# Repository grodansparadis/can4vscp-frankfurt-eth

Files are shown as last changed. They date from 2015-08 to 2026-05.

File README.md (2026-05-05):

<h1>CAN4VSCP Frankfurt Eth (PoE)</h1>

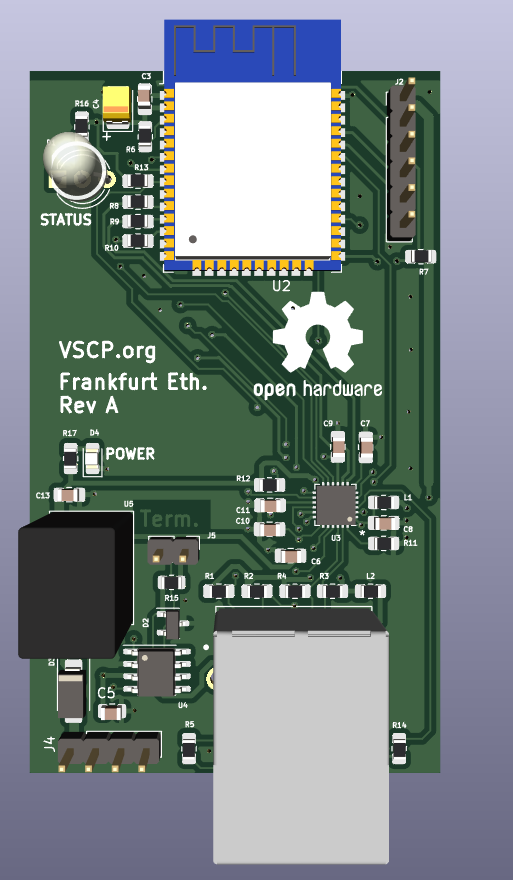
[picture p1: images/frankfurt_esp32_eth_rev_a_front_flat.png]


This work is based on original work done [here](https://github.com/nuclearcat/ESP32ETH). 

**Frankfurt Eth** is a tcp/ip and MQTT CAN4VSCP gateway. The module is available in two versions. One without PoE and and one with PoE.

The module is plug and play. Just connect to a CAN4VSCP system and go to work. You can connect to the module using [VSCP tcp/ip link protocol](https://grodansparadis.github.io/vscp-doc-spec/#/./vscp_tcpiplink) or set it up to talk to a MQTT broker of choice.

Note that this is **not** a CAN <-> tcp/ip (or MQTT) gateway as it only speaks [VSCP](https://grodansparadis.github.io/vscp-doc-spec). It is possible though to load firmware into it to create a standard CAN (not CAN FD) <-> tcp/ip gateway. 

The project uses an ESP32 Wroom module. It utilize Ethernet instead of Wifi/Bluetooth. Ethernet interface is provided with a LAN8720A and CAN is provided by the ESP32 support for TWAI. The module is powered from the [CAN4VSCP bus](https://grodansparadis.github.io/vscp-doc-spec/#/./vscp_over_can_can4vscp) (or PoE).  When powered from PoE the module can provide power for other CAN4VSCP modules. CAN4VSCP power is in the range +9V - 28V.

The intended use is to connect a remote CAN4VSCP bus to a central system or to connect two or more CAN4VSCP networks together. 

If Wifi is required instead of Ethernet the [CAN4VSCP Frankfurt Wifi module](https://github.com/grodansparadis/can4vscp-frankfurt-wifi) is available that can do that.



Prototype PCB's for this project has been sponsored by [PCBWay](https://www.pcbway.com/). We can really recommend this service if you need high quality PCB's. 

## Schema

### Standard version

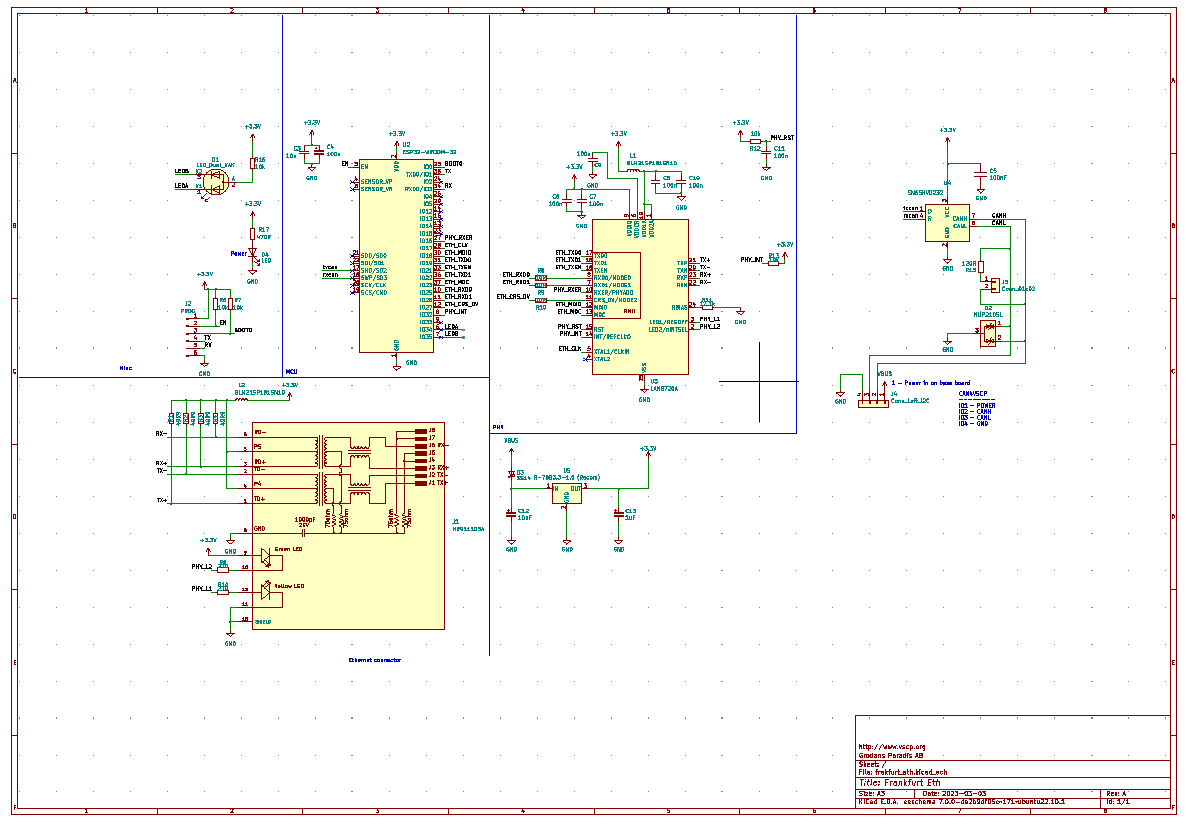
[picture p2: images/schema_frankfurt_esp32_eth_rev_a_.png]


### PoE version

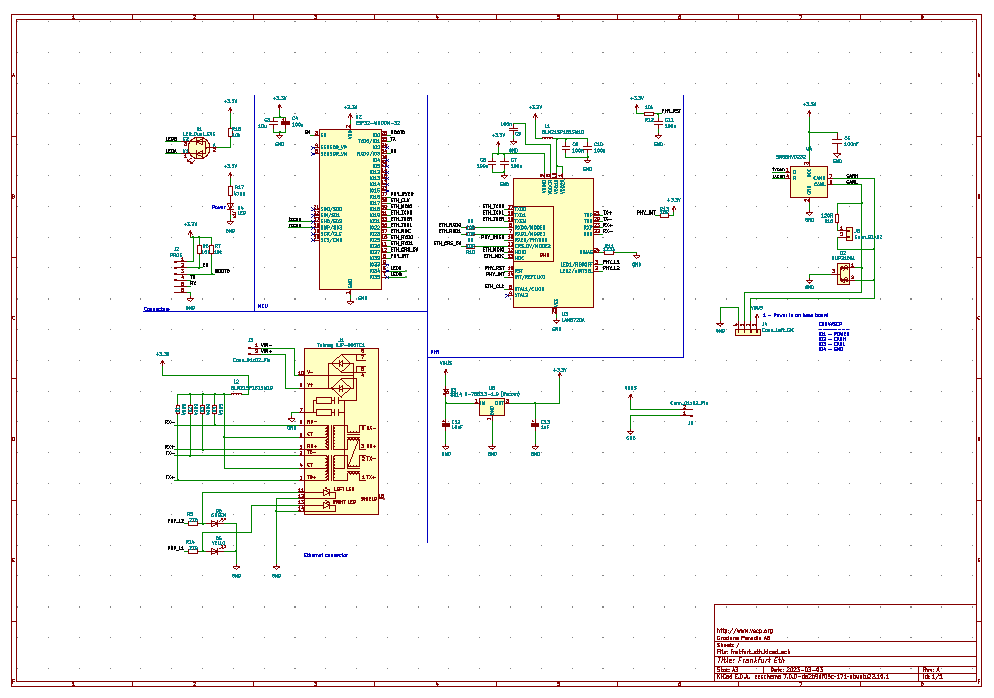
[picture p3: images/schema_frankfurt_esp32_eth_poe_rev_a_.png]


## Standard version

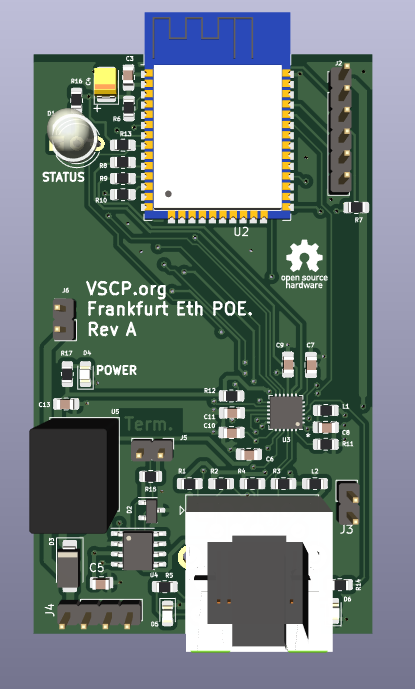
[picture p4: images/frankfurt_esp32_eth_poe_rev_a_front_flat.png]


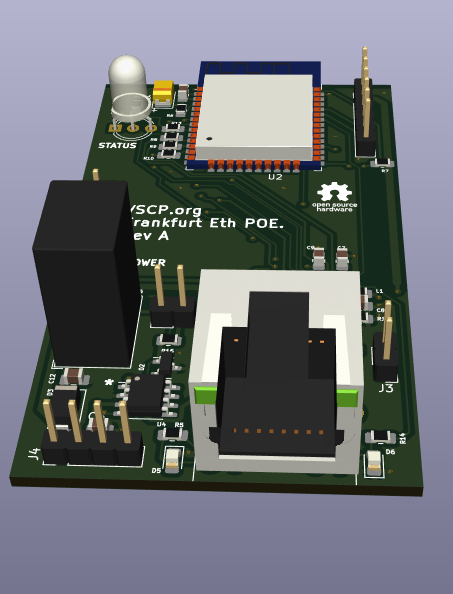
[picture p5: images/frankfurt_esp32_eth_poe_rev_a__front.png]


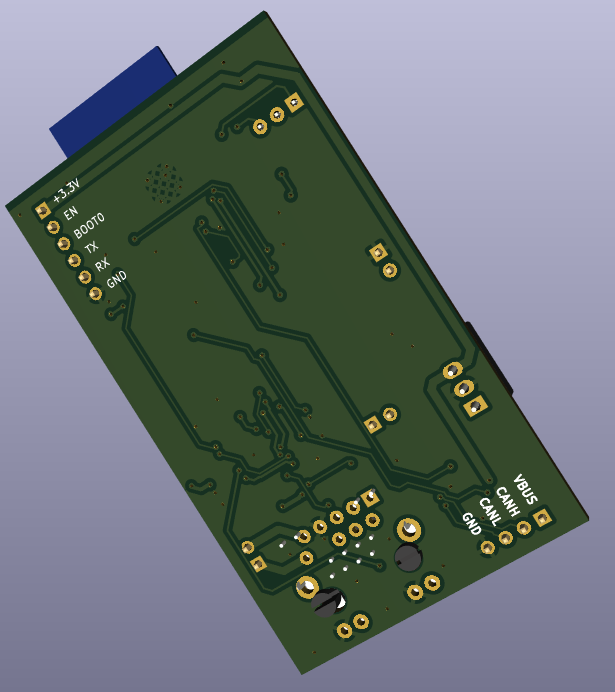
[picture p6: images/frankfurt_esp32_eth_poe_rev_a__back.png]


## PoE Version



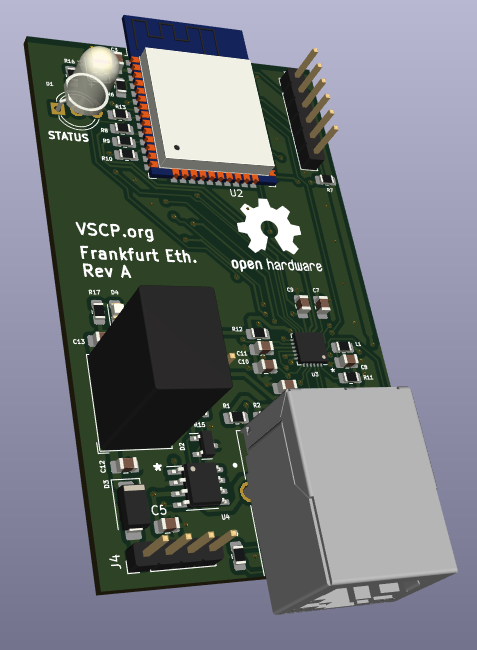
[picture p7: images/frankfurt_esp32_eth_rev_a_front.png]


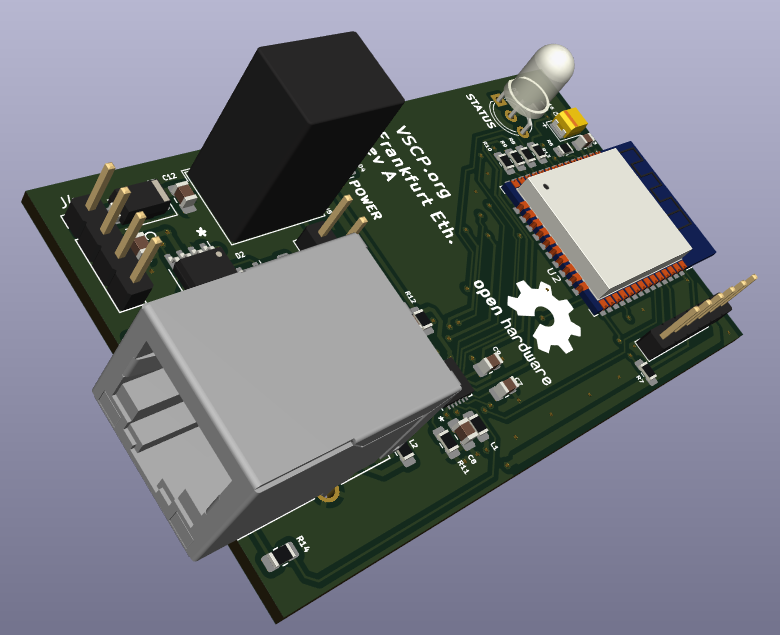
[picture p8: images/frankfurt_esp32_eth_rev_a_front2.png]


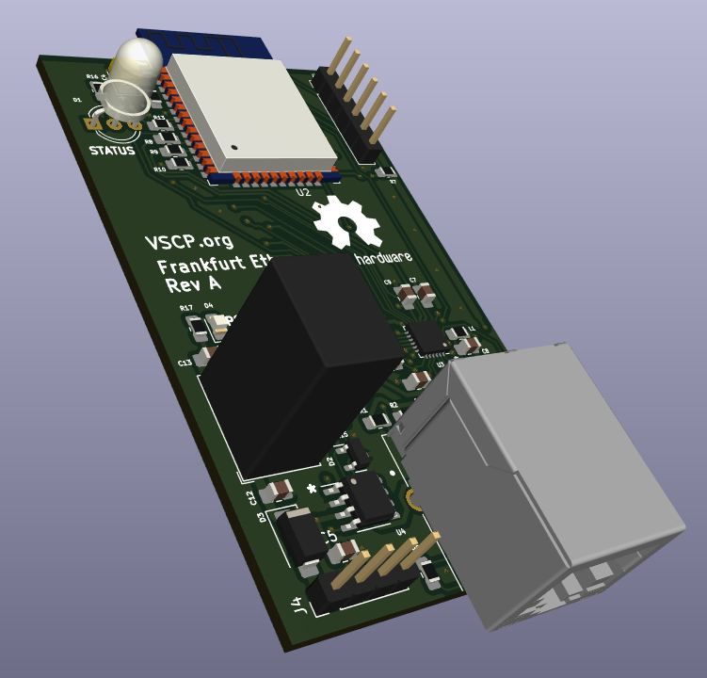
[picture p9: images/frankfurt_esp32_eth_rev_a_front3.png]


<hr>
Please support the <a href="http://www.vscp.org">VSCP development</a>. The best way to support the project is 
to buy something from the <a href="http://www.frogshop.se">FrogShop</a>. If you want to contribute money use the button
 at the end of the <a href="http://www.vscp.org">VSCP sites</a> start page.

Visit our <a href="http://www.vscp.org/wiki/doku.php/sponsors">sponsor page</a> for all options.

<hr>

Part of the VSCP Project.

Copyright 2018-2026 © Åke Hedman, (Grodans Paradis AB)[https://www.grodansparadis.com]

<hr>

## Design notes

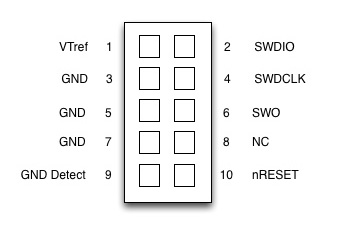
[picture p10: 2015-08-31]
pic-version/docs/swd-jtag-pinout.jpg

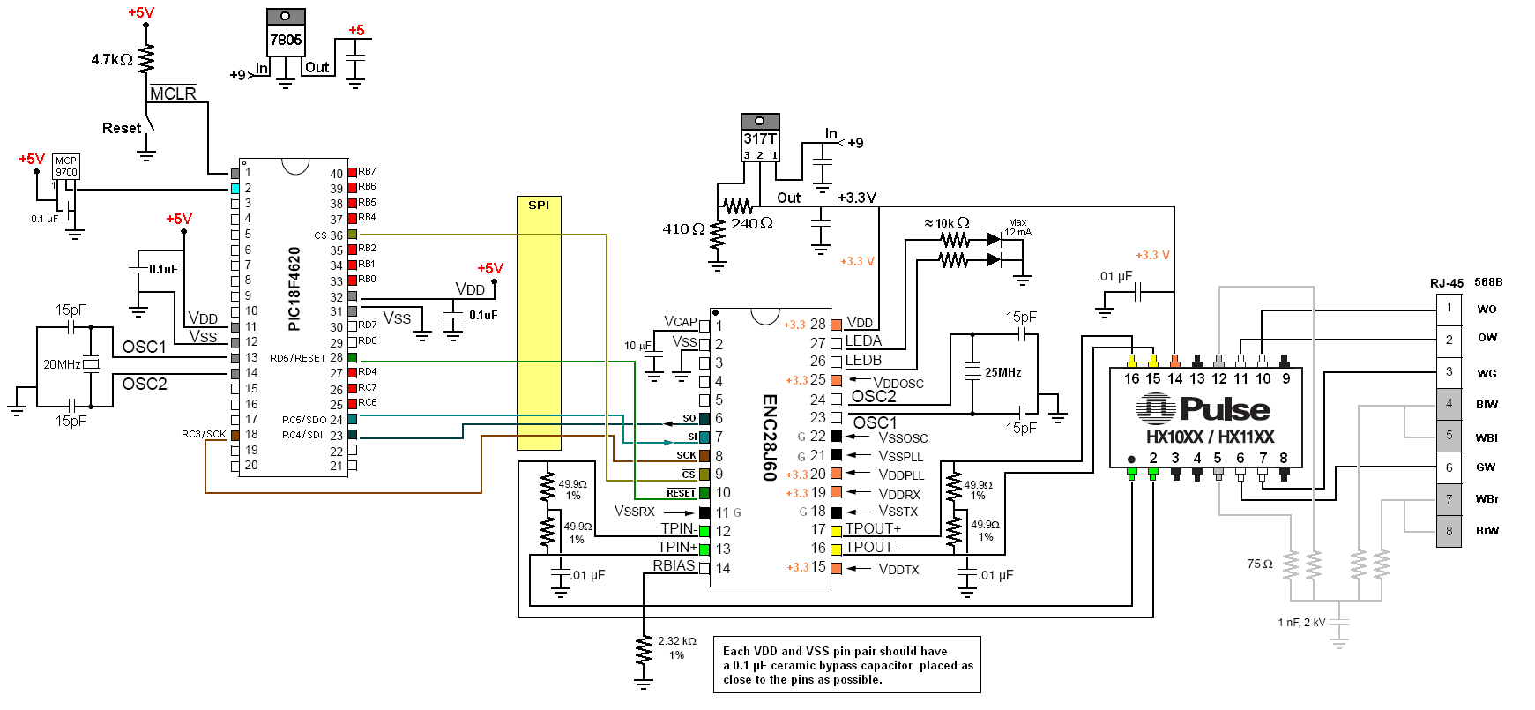
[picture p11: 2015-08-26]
pic-version/docs/eth-schematic-ab.png

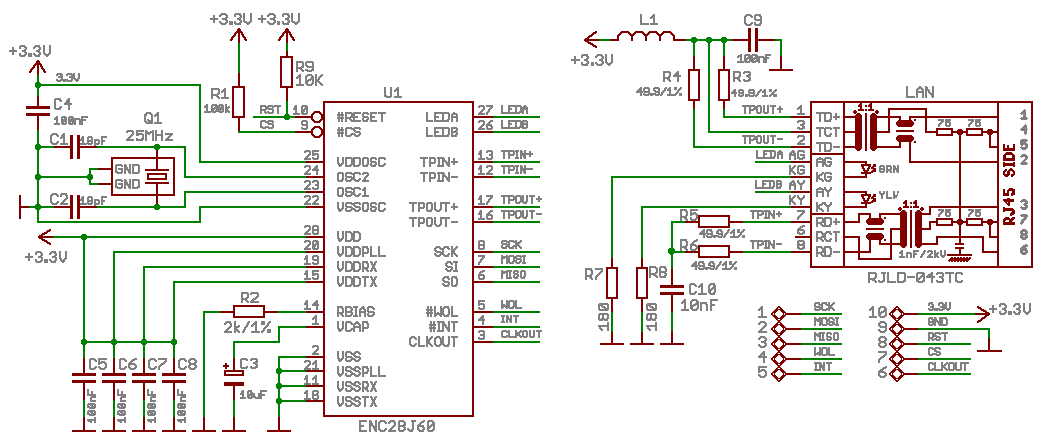
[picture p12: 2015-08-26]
pic-version/docs/enc28j60_h_schematic_full.png

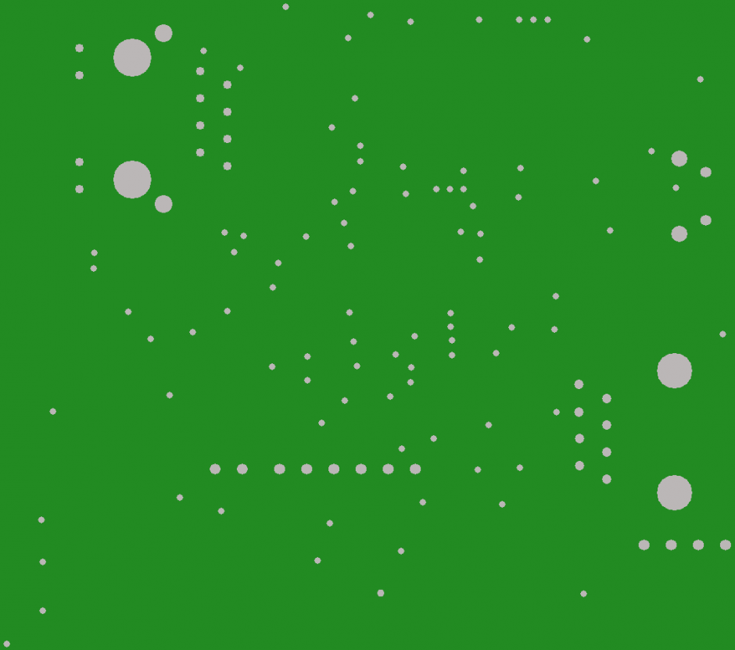
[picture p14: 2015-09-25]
pic-version/eagle/Gerbers/pic/frankfurt_eth_pic_gerbers_150925_txt_small.png

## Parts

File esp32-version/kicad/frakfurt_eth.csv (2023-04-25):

Source: | /usr/local/src/VSCP/can4vscp-frankfurt-eth/esp32-version/kicad/frakfurt_eth.kicad_sch
Date: | tor 23 mar 2023 16:47:27
Tool: | Eeschema 7.0.1-3b83917a11~172~ubuntu22.10.1
Generator: | /usr/share/kicad/plugins/bom_csv_grouped_by_value_with_fp.py
Component Count: | 42
Ref | Qnty | Value | Cmp name | Footprint | Description | Vendor | DNP
C3 | 1 | 10u | C_Small | Capacitor_SMD:C_0805_2012Metric_Pad1.18x1.45mm_HandSolder | Unpolarized capacitor, small symbol
C4 | 1 | 100u | C_Polarized_Small | Capacitor_Tantalum_SMD:CP_EIA-3528-21_Kemet-B | Polarized capacitor, small symbol
C5 | 1 | 100nF | C | Capacitor_SMD:C_0805_2012Metric | Unpolarized capacitor
C6, C7, C8, C9, C10, C11 | 6 | 100n | C_Small | Capacitor_SMD:C_0805_2012Metric_Pad1.18x1.45mm_HandSolder | Unpolarized capacitor, small symbol
C12 | 1 | 10uF | CP_Small | Capacitor_SMD:C_0805_2012Metric_Pad1.18x1.45mm_HandSolder
C13 | 1 | 1uF | CP_Small | Capacitor_SMD:C_0805_2012Metric_Pad1.18x1.45mm_HandSolder
D1 | 1 | LED_Dual_KAK | LED_Dual_KAK | LED_THT:LED_D5.0mm-3 | Dual LED, common anode on pin 2
D2 | 1 | NUP2105L | NUP2105L | Package_TO_SOT_SMD:SOT-23 | Dual Line CAN Bus Protector, 24Vrwm
D3 | 1 | SS14 | D_Schottky_Small | Diode_SMD:D_SMA | Schottky diode, small symbol
D4 | 1 | LED | LED | LED_SMD:LED_0805_2012Metric_Pad1.15x1.40mm_HandSolder | Light emitting diode
J1 | 1 | HR911105A | HR911105A | lib:HANRUN_HR911105A
J2 | 1 | PROG | Conn_01x06_Male | Connector_PinHeader_2.54mm:PinHeader_1x06_P2.54mm_Vertical | Generic connector, single row, 01x06, script generated (kicad-library-utils/schlib/autogen/connector/)
J4 | 1 | Conn_Left_I2C | Conn_01x04 | Connector_PinHeader_2.54mm:PinHeader_1x04_P2.54mm_Vertical | Generic connector, single row, 01x04, script generated (kicad-library-utils/schlib/autogen/connector/)
J5 | 1 | Conn_01x02 | Conn_01x02 | Connector_PinHeader_2.54mm:PinHeader_1x02_P2.54mm_Vertical | Generic connector, single row, 01x02, script generated (kicad-library-utils/schlib/autogen/connector/)
L1, L2 | 2 | BLM21SP181SN1D | L_Small | Resistor_SMD:R_0805_2012Metric_Pad1.20x1.40mm_HandSolder | Inductor, small symbol
R1, R2, R3, R4 | 4 | 49R9 | R_Small | Resistor_SMD:R_0805_2012Metric_Pad1.20x1.40mm_HandSolder | Resistor, small symbol
R5, R14 | 2 | 270 | R_Small | Resistor_SMD:R_0805_2012Metric_Pad1.20x1.40mm_HandSolder | Resistor, small symbol
R6, R7, R12, R13, R16 | 5 | 10k | R_Small | Resistor_SMD:R_0805_2012Metric_Pad1.20x1.40mm_HandSolder | Resistor, small symbol
R8, R9, R10 | 3 | 10R | R_Small | Resistor_SMD:R_0805_2012Metric_Pad1.20x1.40mm_HandSolder | Resistor, small symbol
R11 | 1 | 12.1k | R_Small | Resistor_SMD:R_0805_2012Metric_Pad1.20x1.40mm_HandSolder | Resistor, small symbol
R15 | 1 | 120R | R_Small | Resistor_SMD:R_0805_2012Metric | Resistor, small symbol
R17 | 1 | 470R | R_Small | Resistor_SMD:R_0805_2012Metric_Pad1.20x1.40mm_HandSolder | Resistor, small symbol
U2 | 1 | ESP32-WROOM-32 | ESP32-WROOM-32 | RF_Module:ESP32-WROOM-32 | RF Module, ESP32-D0WDQ6 SoC, Wi-Fi 802.11b/g/n, Bluetooth, BLE, 32-bit, 2.7-3.6V, onboard antenna, SMD
U3 | 1 | LAN8720A | LAN8720A | Package_DFN_QFN:QFN-24-1EP_4x4mm_P0.5mm_EP2.6x2.6mm | LAN8720 Ethernet PHY with RMII interface, QFN-24
U4 | 1 | SN65HVD232 | SN65HVD232 | Package_SO:SOIC-8_3.9x4.9mm_P1.27mm | CAN Bus Transceivers, 3.3V, 1Mbps, SOIC-8
U5 | 1 | R-78B3.3-1.0 (Recom) | R-78B3.3-2.0 | Converter_DCDC:Converter_DCDC_RECOM_R-78B-2.0_THT | 2A Step-Down DC/DC-Regulator, 4.75-32V input, 3.3V fixed Output Voltage, LM78xx replacement, -40°C to +85°C, SIP3

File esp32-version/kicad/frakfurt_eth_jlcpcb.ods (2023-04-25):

Source: | /usr/local/src/VSCP/can4vscp-frankfurt-eth/esp32-version/kicad/frakfurt_eth.kicad_sch
Date: | tor 23 mar 2023 16:47:27
Tool: | Eeschema 7.0.1-3b83917a11~172~ubuntu22.10.1
Generator: | /usr/share/kicad/plugins/bom_csv_grouped_by_value_with_fp.py
Component Count: | 42
Ref | Qnty | Value | Cmp name | Footprint | Description | Vendor | DNP | JLCPCB
C3 | 1 | 10u | C_Small | Capacitor_SMD:C_0805_2012Metric_Pad1.18x1.45mm_HandSolder | Unpolarized capacitor, small symbol |  |  | 0.18 | 0.1793
C4 | 1 | 100u | C_Polarized_Small | Capacitor_Tantalum_SMD:CP_EIA-3528-21_Kemet-B | Polarized capacitor, small symbol |  |  | 0.01 | 0.0057
C5 | 1 | 100nF | C | Capacitor_SMD:C_0805_2012Metric | Unpolarized capacitor |  |  | 0.0057 | 0.0057
C6, C7, C8, C9, C10, C11 | 6 | 100n | C_Small | Capacitor_SMD:C_0805_2012Metric_Pad1.18x1.45mm_HandSolder | Unpolarized capacitor, small symbol |  |  | 0.0057 | 0.0342
C12 | 1 | 10uF | CP_Small | Capacitor_SMD:C_0805_2012Metric_Pad1.18x1.45mm_HandSolder |  |  |  | 0.0057 | 0.0057
C13 | 1 | 1uF | CP_Small | Capacitor_SMD:C_0805_2012Metric_Pad1.18x1.45mm_HandSolder |  |  |  | 0.0057 | 0.0057
D1 | 1 | LED_Dual_KAK | LED_Dual_KAK | LED_THT:LED_D5.0mm-3 | Dual LED, common anode on pin 2 |  |  | 0.00 | 0
D2 | 1 | NUP2105L | NUP2105L | Package_TO_SOT_SMD:SOT-23 | Dual Line CAN Bus Protector, 24Vrwm |  |  | 0.04 | 0.0444
D3 | 1 | SS14 | D_Schottky_Small | Diode_SMD:D_SMA | Schottky diode, small symbol |  |  | 0.02 | 0.017
D4 | 1 | LED | LED | LED_SMD:LED_0805_2012Metric_Pad1.15x1.40mm_HandSolder | Light emitting diode |  |  | 0.04 | 0.0386
J1 | 1 | HR911105A | HR911105A | lib:HANRUN_HR911105A |  |  |  | 1.36 | 1.36
J2 | 1 | PROG | Conn_01x06_Male | Connector_PinHeader_2.54mm:PinHeader_1x06_P2.54mm_Vertical | Generic connector, single row, 01x06, script generated (kicad-library-utils/schlib/autogen/connector/) |  |  | 0.00 | 0 | https://jlcpcb.com/parts/componentSearch?searchTxt=termination%20block%202.54%204p
J4 | 1 | Conn_Left_I2C | Conn_01x04 | Connector_PinHeader_2.54mm:PinHeader_1x04_P2.54mm_Vertical | Generic connector, single row, 01x04, script generated (kicad-library-utils/schlib/autogen/connector/) |  |  | 0.23 | 0.2278 | https://jlcpcb.com/partdetail/Cixi_KefaElec-KF2EDGR_2_544P/C577596
J5 | 1 | Conn_01x02 | Conn_01x02 | Connector_PinHeader_2.54mm:PinHeader_1x02_P2.54mm_Vertical | Generic connector, single row, 01x02, script generated (kicad-library-utils/schlib/autogen/connector/) |  |  | 0.02 | 0.0206
L1, L2 | 2 | BLM21SP181SN1D | L_Small | Resistor_SMD:R_0805_2012Metric_Pad1.20x1.40mm_HandSolder | Inductor, small symbol |  |  | 0.0021 | 0.0042
R1, R2, R3, R4 | 4 | 49R9 | R_Small | Resistor_SMD:R_0805_2012Metric_Pad1.20x1.40mm_HandSolder | Resistor, small symbol |  |  | 0.0021 | 0.0084
R5, R14 | 2 | 270 | R_Small | Resistor_SMD:R_0805_2012Metric_Pad1.20x1.40mm_HandSolder | Resistor, small symbol |  |  | 0.0021 | 0.0042
R6, R7, R12, R13, R16 | 5 | 10k | R_Small | Resistor_SMD:R_0805_2012Metric_Pad1.20x1.40mm_HandSolder | Resistor, small symbol |  |  | 0.0021 | 0.0105
R8, R9, R10 | 3 | 10R | R_Small | Resistor_SMD:R_0805_2012Metric_Pad1.20x1.40mm_HandSolder | Resistor, small symbol |  |  | 0.0021 | 0.0063
R11 | 1 | 12.1k | R_Small | Resistor_SMD:R_0805_2012Metric_Pad1.20x1.40mm_HandSolder | Resistor, small symbol |  |  | 0.0021 | 0.0021
R15 | 1 | 120R | R_Small | Resistor_SMD:R_0805_2012Metric | Resistor, small symbol |  |  | 0.0021 | 0.0021
R17 | 1 | 470R | R_Small | Resistor_SMD:R_0805_2012Metric_Pad1.20x1.40mm_HandSolder | Resistor, small symbol |  |  | 0.0021 | 0.0021
U2 | 1 | ESP32-WROOM-32 | ESP32-WROOM-32 | RF_Module:ESP32-WROOM-32 | RF Module, ESP32-D0WDQ6 SoC, Wi-Fi 802.11b/g/n, Bluetooth, BLE, 32-bit, 2.7-3.6V, onboard antenna, SMD |  |  | 3.36 | 3.36
U3 | 1 | LAN8720A | LAN8720A | Package_DFN_QFN:QFN-24-1EP_4x4mm_P0.5mm_EP2.6x2.6mm | LAN8720 Ethernet PHY with RMII interface, QFN-24 |  |  | 2.47 | 2.4652
U4 | 1 | SN65HVD232 | SN65HVD232 | Package_SO:SOIC-8_3.9x4.9mm_P1.27mm | CAN Bus Transceivers, 3.3V, 1Mbps, SOIC-8 |  |  | 1.22 | 1.2209
U5 | 1 | R-78B3.3-1.0 (Recom) | R-78B3.3-2.0 | Converter_DCDC:Converter_DCDC_RECOM_R-78B-2.0_THT K7803JT-500R3-LB | 2A Step-Down DC/DC-Regulator, 4.75-32V input, 3.3V fixed Output Voltage, LM78xx replacement, -40°C to +85°C, SIP3 |  |  | 2.04 | 2.0405 | https://jlcpcb.com/partdetail/6219383-K7803JT_500R3LB/C5371628
 |  |  |  |  |  |  |  |  | 11.0712

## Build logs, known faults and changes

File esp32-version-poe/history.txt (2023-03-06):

History Frankfurt-eth (esp32/poe)
=================================

230306 - AKHE - Beginning of history

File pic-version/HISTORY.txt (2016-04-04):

2016-04-04 AKHE - Changed value of C14 to 10uF

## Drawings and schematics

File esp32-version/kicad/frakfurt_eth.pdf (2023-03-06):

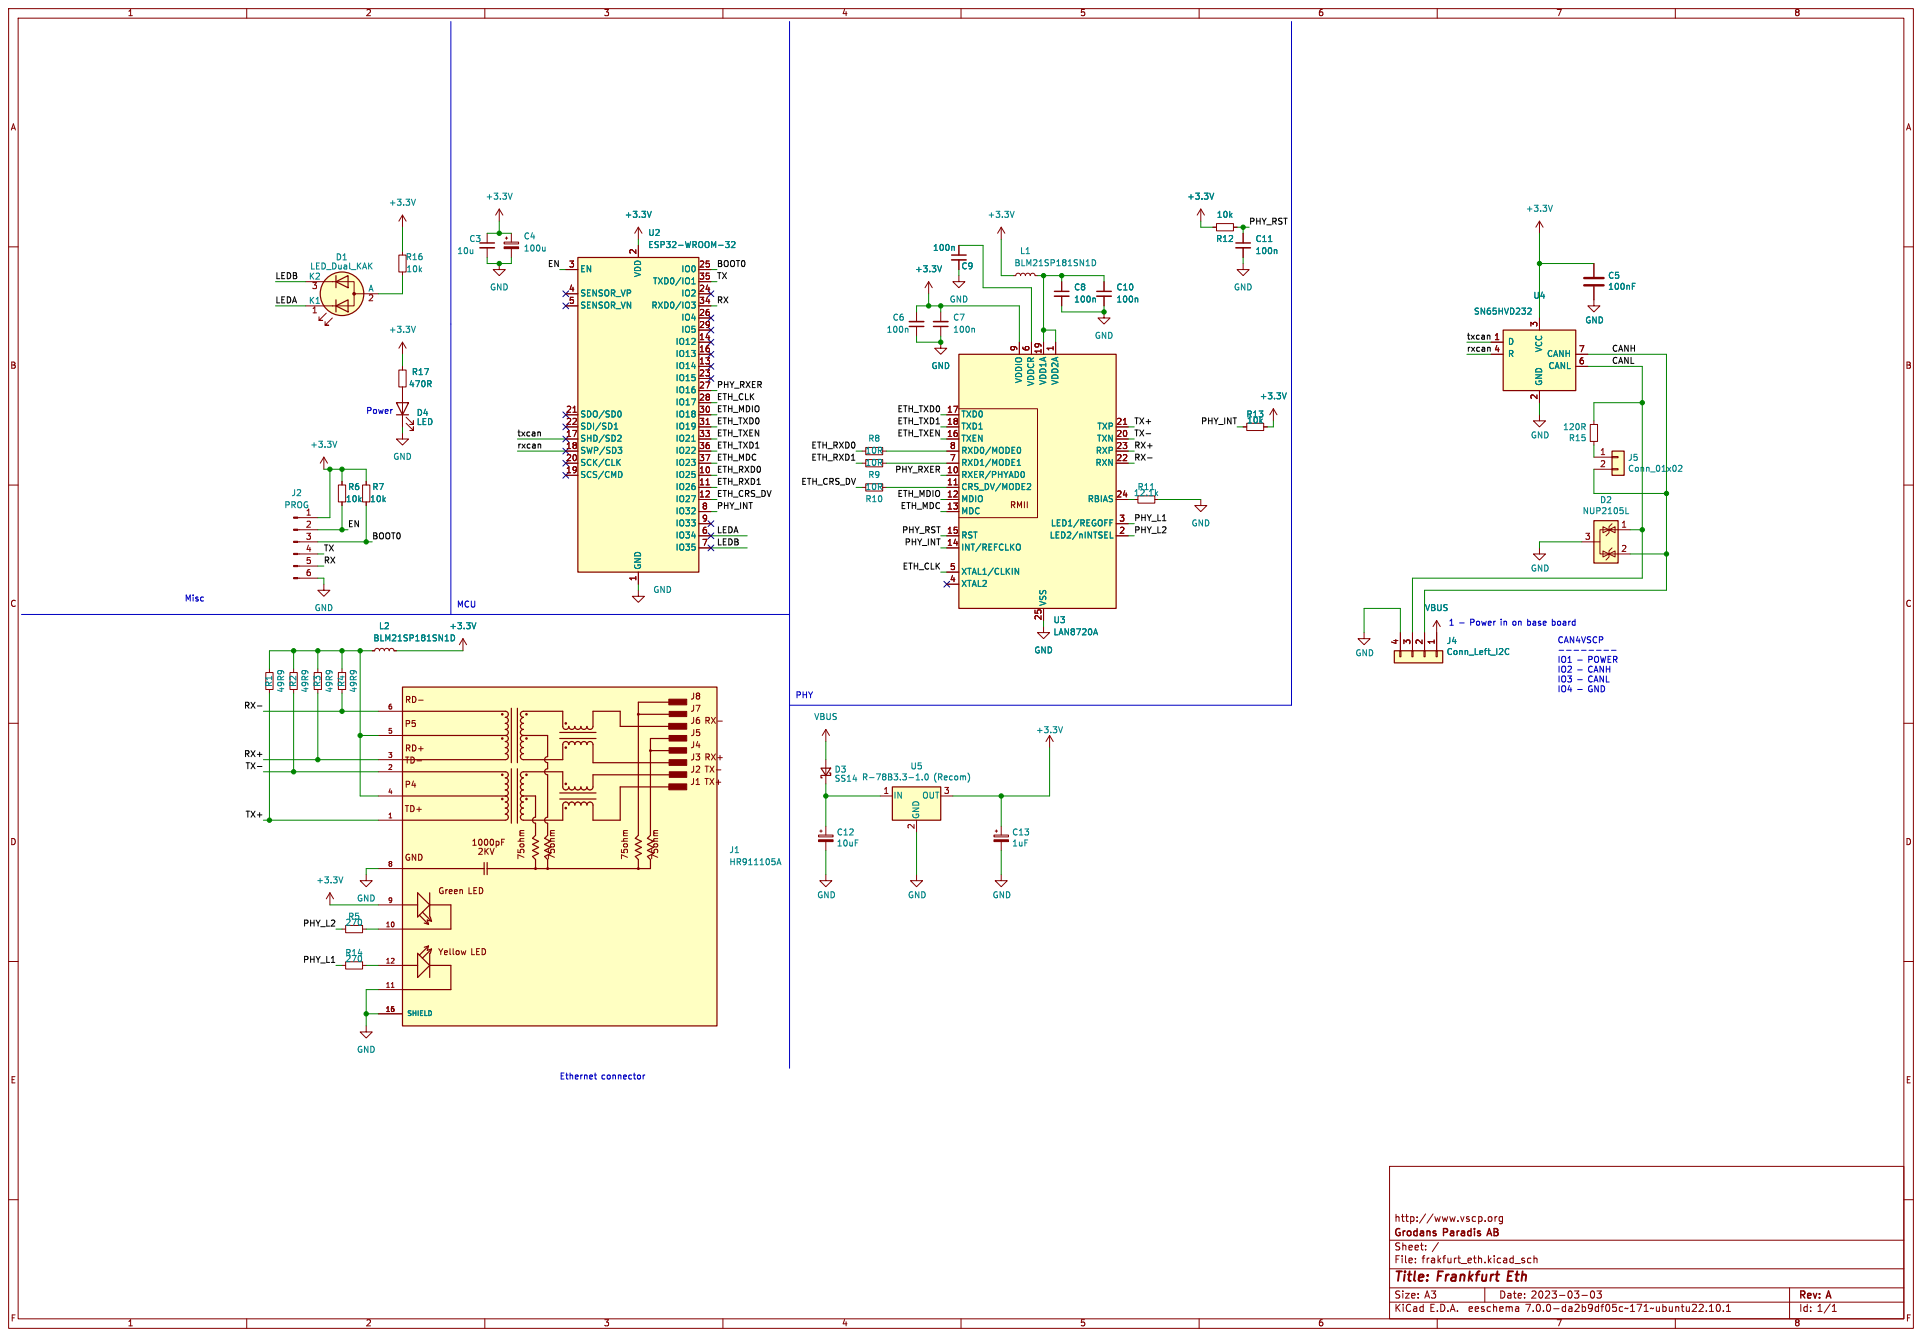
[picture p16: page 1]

2 SCK/CLK 20 SDO/SD0 21 SDI/SD1 22

http://www.vscp.org

Id: 1/1 Title: Frankfurt Eth

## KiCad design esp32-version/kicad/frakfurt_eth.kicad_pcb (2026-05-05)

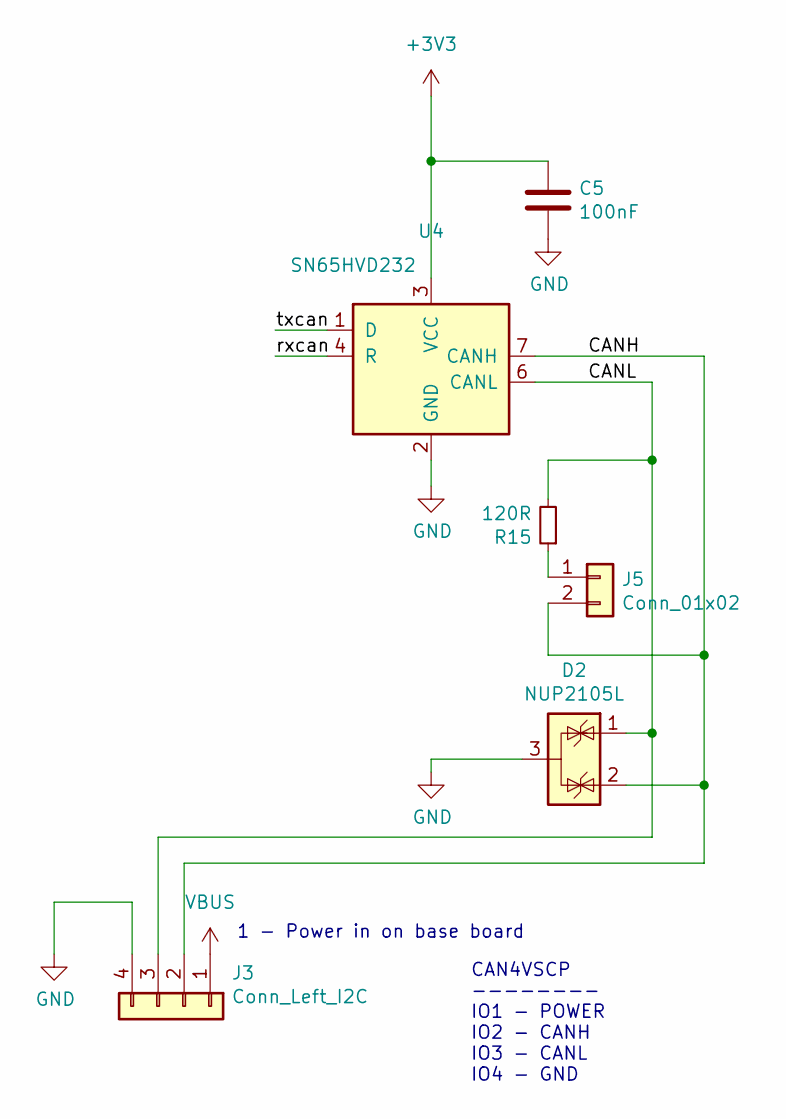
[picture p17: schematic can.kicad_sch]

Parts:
C5: 100nF; C_0805_2012Metric
D2: NUP2105L; SOT-23
J3: Conn_Left_I2C; PinHeader_1x04_P2.54mm_Vertical
J5: Conn_01x02; PinHeader_1x02_P2.54mm_Vertical
R15: 120R; R_0805_2012Metric
U4: SN65HVD232; SOIC-8_3.9x4.9mm_P1.27mm

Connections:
/CANH: D2.2 (K), J3.2, J5.2, U4.7 (CANH); also elsewhere on the board
/CANL: D2.1 (K), J3.3, R15.2, U4.6 (CANL); also elsewhere on the board
/rxcan: U4.4 (R); also elsewhere on the board
/txcan: U4.1 (D); also elsewhere on the board
GND: C5.2, D2.3 (A), J3.4, U4.2 (GND); also elsewhere on the board
unnamed: J5.1, R15.1

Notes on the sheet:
1 - Power in on base board
CAN4VSCP -------- IO1 - POWER IO2 - CANH IO3 - CANL IO4 - GND

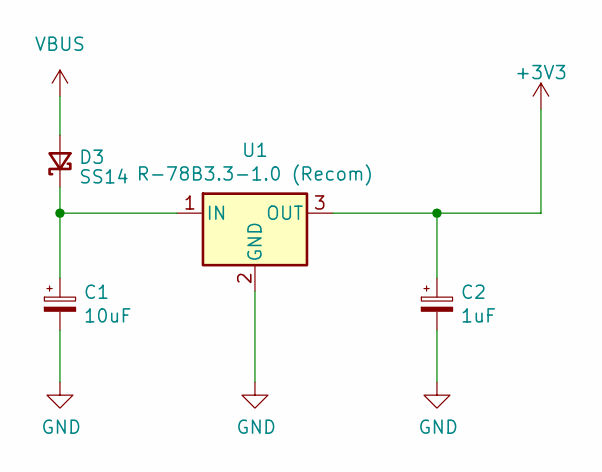
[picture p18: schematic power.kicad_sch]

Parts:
C1: 10uF; C_0805_2012Metric_Pad1.18x1.45mm_HandSolder
C2: 1uF; C_0805_2012Metric_Pad1.18x1.45mm_HandSolder
D3: SS14; D_SMA
U1: R-78B3.3-1.0 (Recom); Converter_DCDC_RECOM_R-78B-2.0_THT

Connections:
unnamed: C1.2, C2.2, U1.2 (GND)
unnamed: C2.1, U1.3 (OUT)
unnamed 31: C1.1, D3.1 (K), U1.1 (IN); also elsewhere on the board
VBUS: D3.2 (A); also elsewhere on the board

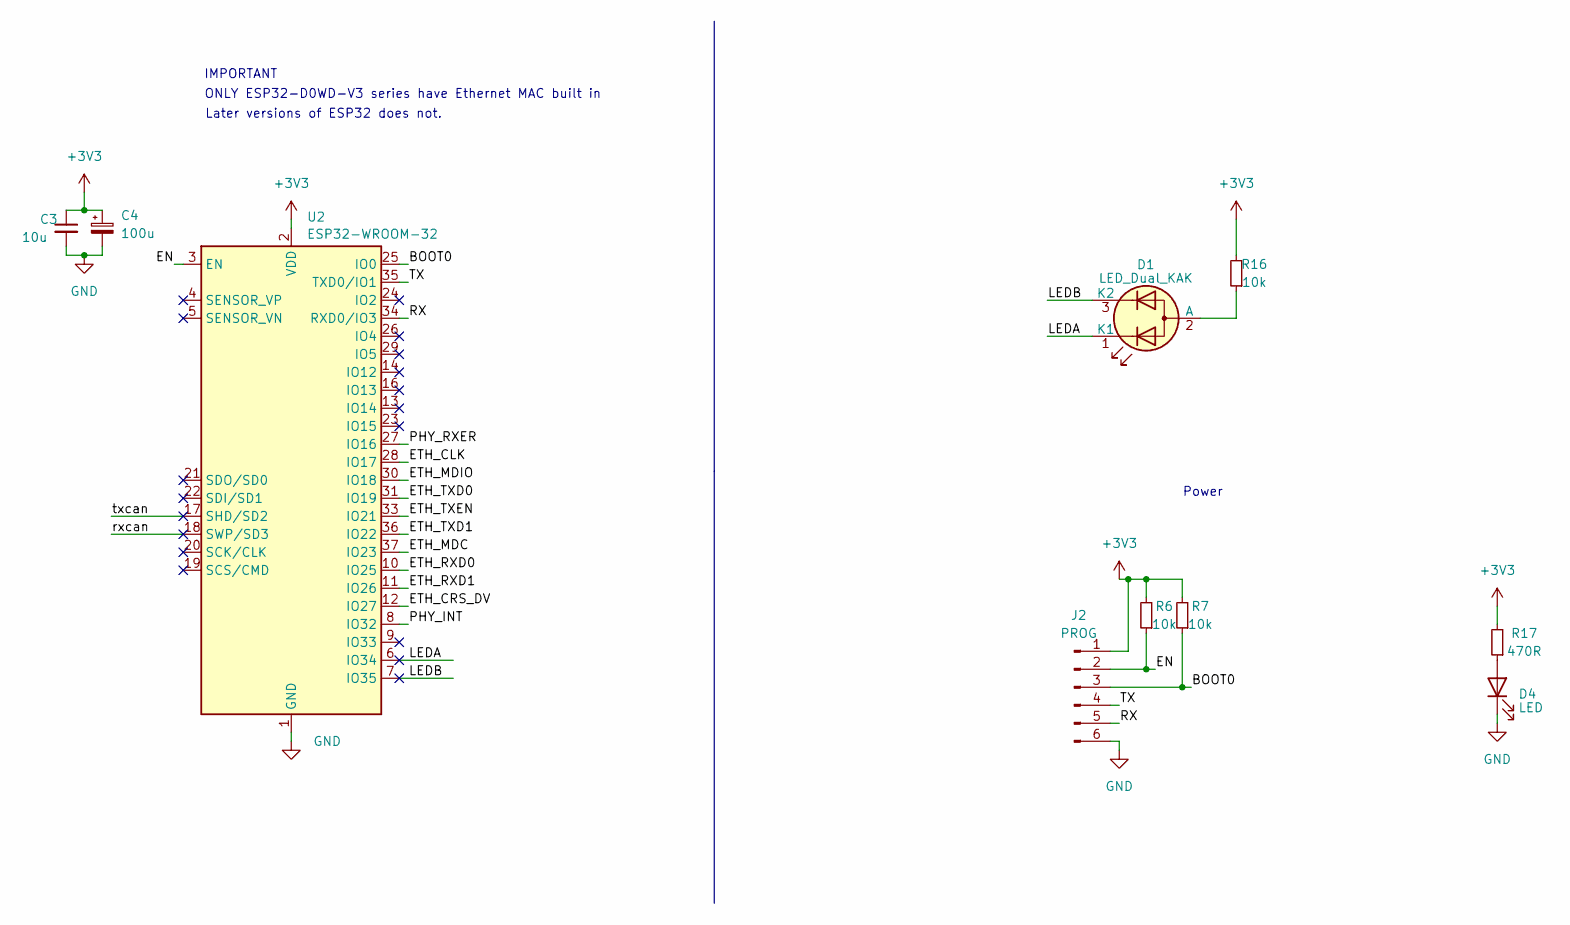
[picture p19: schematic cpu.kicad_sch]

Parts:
C3: 10u; C_0805_2012Metric_Pad1.18x1.45mm_HandSolder
C4: 100u; CP_EIA-3528-21_Kemet-B
D1: LED_Dual_KAK; LED_D5.0mm-3
D4: LED; LED_0805_2012Metric_Pad1.15x1.40mm_HandSolder
J2: PROG; PinHeader_1x06_P2.54mm_Vertical
R6, R7, R16: 10k; R_0805_2012Metric_Pad1.20x1.40mm_HandSolder
R17: 470R; R_0805_2012Metric_Pad1.20x1.40mm_HandSolder
U2: ESP32-WROOM-32

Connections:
/BOOT0: J2.3, R7.1, U2.25 (IO0)
/EN: J2.2, R6.1, U2.3 (EN)
/ETH_CLK: U2.28 (IO17); also elsewhere on the board
/ETH_CRS_DV: U2.12 (IO27); also elsewhere on the board
/ETH_MDC: U2.37 (IO23); also elsewhere on the board
/ETH_MDIO: U2.30 (IO18); also elsewhere on the board
/ETH_RXD0: U2.10 (IO25); also elsewhere on the board
/ETH_RXD1: U2.11 (IO26); also elsewhere on the board
/ETH_TXD0: U2.31 (IO19); also elsewhere on the board
/ETH_TXD1: U2.36 (IO22); also elsewhere on the board
/ETH_TXEN: U2.33 (IO21); also elsewhere on the board
/LEDA: D1.1 (K1), U2.6 (IO34)
/LEDB: D1.3 (K2), U2.7 (IO35)
/PHY_INT: U2.8 (IO32); also elsewhere on the board
/PHY_RXER: U2.27 (IO16); also elsewhere on the board
/RX: J2.5, U2.34 (RXD0/IO3)
/TX: J2.4, U2.35 (TXD0/IO1)
/rxcan: U2.18 (SWP/SD3); also elsewhere on the board
/txcan: U2.17 (SHD/SD2); also elsewhere on the board
GND: C3.2, C4.2, D4.1 (K), J2.6, U2.1 (GND), U2.15 (GND), U2.38 (GND), U2.39 (GND); also elsewhere on the board
unnamed: D1.2 (A), R16.1
unnamed: D4.2 (A), R17.1

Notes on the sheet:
Later versions of ESP32 does not.
ONLY ESP32-D0WD-V3 series have Ethernet MAC built in
IMPORTANT
Power

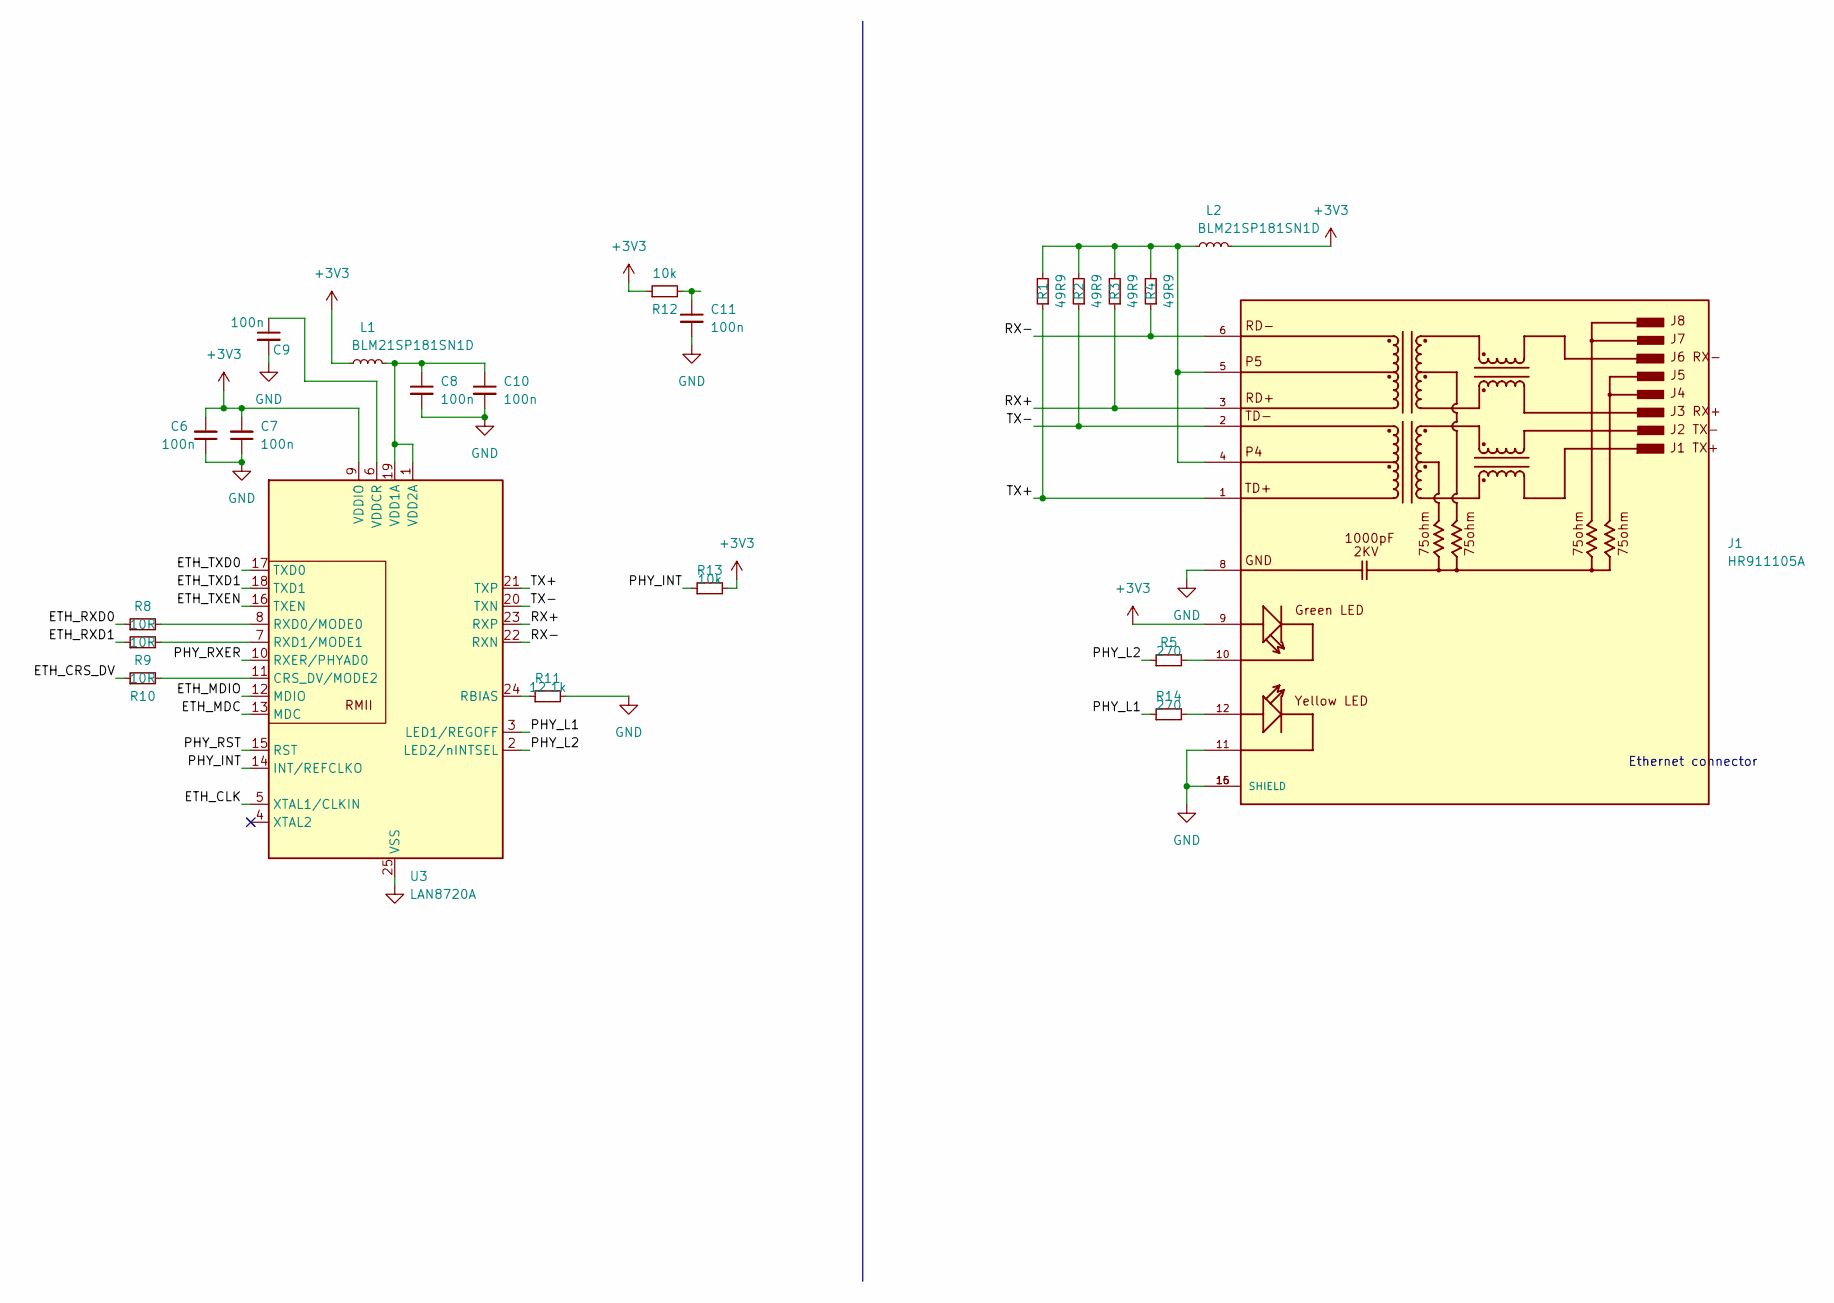
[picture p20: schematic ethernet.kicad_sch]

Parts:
C6, C7, C8, C9, C10, C11: 100n; C_0805_2012Metric_Pad1.18x1.45mm_HandSolder
J1: HR911105A; HANRUN_HR911105A; PARTREV A
L1, L2: BLM21SP181SN1D; R_0805_2012Metric_Pad1.20x1.40mm_HandSolder
R1, R2, R3, R4: 49R9; R_0805_2012Metric_Pad1.20x1.40mm_HandSolder
R5, R14: 270; R_0805_2012Metric_Pad1.20x1.40mm_HandSolder
R8, R9, R10: 10R; R_0805_2012Metric_Pad1.20x1.40mm_HandSolder
R11: 12.1k; R_0805_2012Metric_Pad1.20x1.40mm_HandSolder
R12, R13: 10k; R_0805_2012Metric_Pad1.20x1.40mm_HandSolder
U3: LAN8720A; QFN-24-1EP_4x4mm_P0.5mm_EP2.6x2.6mm

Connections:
/ETH_CLK: U3.5 (XTAL1/CLKIN); also elsewhere on the board
/ETH_CRS_DV: R10.1; also elsewhere on the board
/ETH_MDC: U3.13 (MDC); also elsewhere on the board
/ETH_MDIO: U3.12 (MDIO); also elsewhere on the board
/ETH_RXD0: R8.1; also elsewhere on the board
/ETH_RXD1: R9.1; also elsewhere on the board
/ETH_TXD0: U3.17 (TXD0); also elsewhere on the board
/ETH_TXD1: U3.18 (TXD1); also elsewhere on the board
/ETH_TXEN: U3.16 (TXEN); also elsewhere on the board
/PHY_INT: R13.1, U3.14 (INT/REFCLKO); also elsewhere on the board
/PHY_L1: R14.1, U3.3 (LED1/REGOFF)
/PHY_L2: R5.1, U3.2 (LED2/nINTSEL)
/PHY_RXER: U3.10 (RXER/PHYAD0); also elsewhere on the board
/RX+: J1.3, R3.1, U3.23 (RXP)
/RX-: J1.6, R4.1, U3.22 (RXN)
/TX+: J1.1, R1.1, U3.21 (TXP)
/TX-: J1.2, R2.1, U3.20 (TXN)
GND: C6.1, C7.1, C8.2, C9.2, C10.2, C11.2, J1.8, J1.11, J1.15 (SHIELD), J1.16 (SHIELD), R11.2, U3.25 (VSS); also elsewhere on the board
unnamed: J1.10, R5.2
unnamed: J1.12, R14.2
unnamed: R10.2, U3.11 (CRS_DV/MODE2)
unnamed: R11.1, U3.24 (RBIAS)
unnamed: R8.2, U3.8 (RXD0/MODE0)
unnamed: R9.2, U3.7 (RXD1/MODE1)
unnamed: C8.1, C10.1, L1.2, U3.1 (VDD2A), U3.19 (VDD1A)
unnamed: C9.1, U3.6 (VDDCR)

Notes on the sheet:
Ethernet connector

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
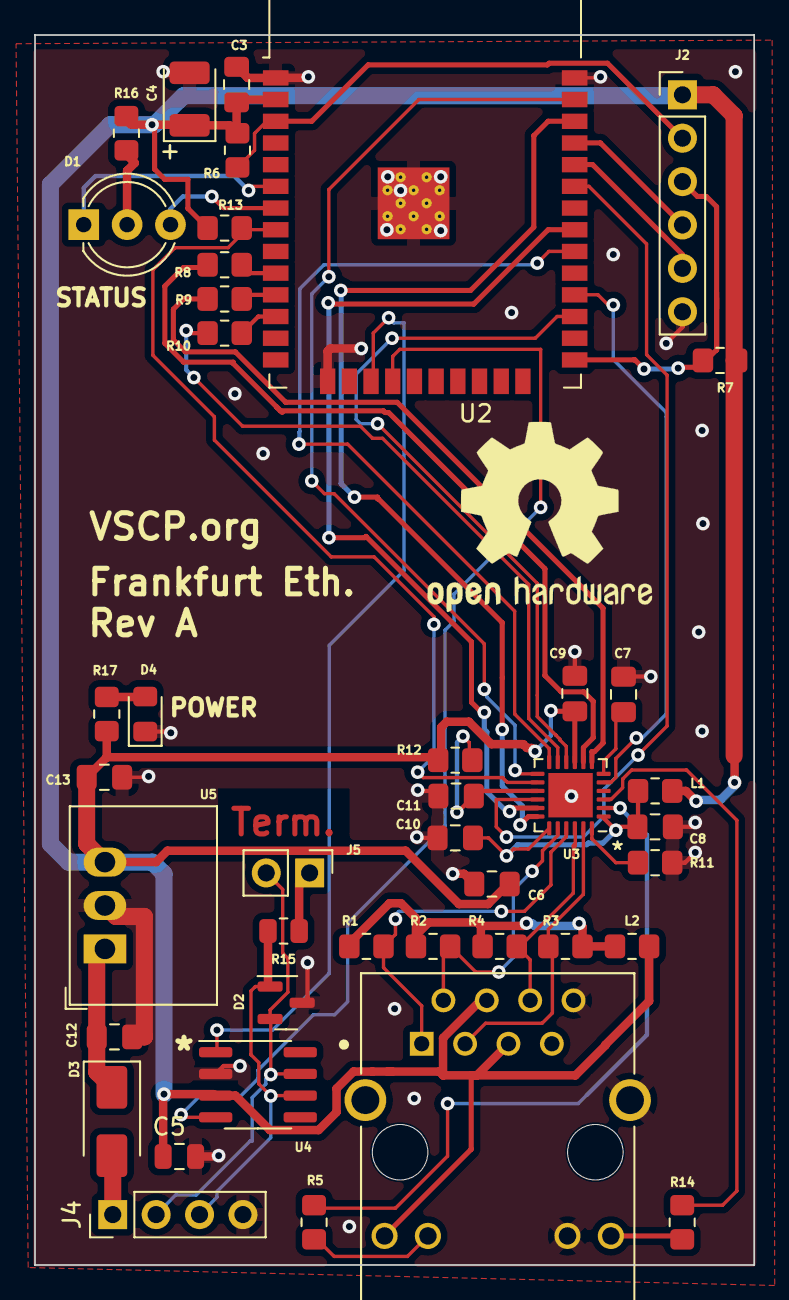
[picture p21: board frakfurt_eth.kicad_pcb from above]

Board: 2 copper layers, 42.1 x 72.0 mm, 42 parts (0 on the bottom side), 44 nets.

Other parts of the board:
C12: 10uF; C_0805_2012Metric_Pad1.18x1.45mm_HandSolder
C13: 1uF; C_0805_2012Metric_Pad1.18x1.45mm_HandSolder
J4: Conn_Left_I2C; PinHeader_1x04_P2.54mm_Vertical
U5: R-78B3.3-1.0 (Recom); Converter_DCDC_RECOM_R-78B-2.0_THT

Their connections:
/CANH: J4.2; also elsewhere on the board
/CANL: J4.3; also elsewhere on the board
GND: C12.2, C13.2, J4.4, U5.2 (GND); also elsewhere on the board
unnamed 31: C12.1, U5.1 (IN); also elsewhere on the board
VBUS: J4.1; also elsewhere on the board

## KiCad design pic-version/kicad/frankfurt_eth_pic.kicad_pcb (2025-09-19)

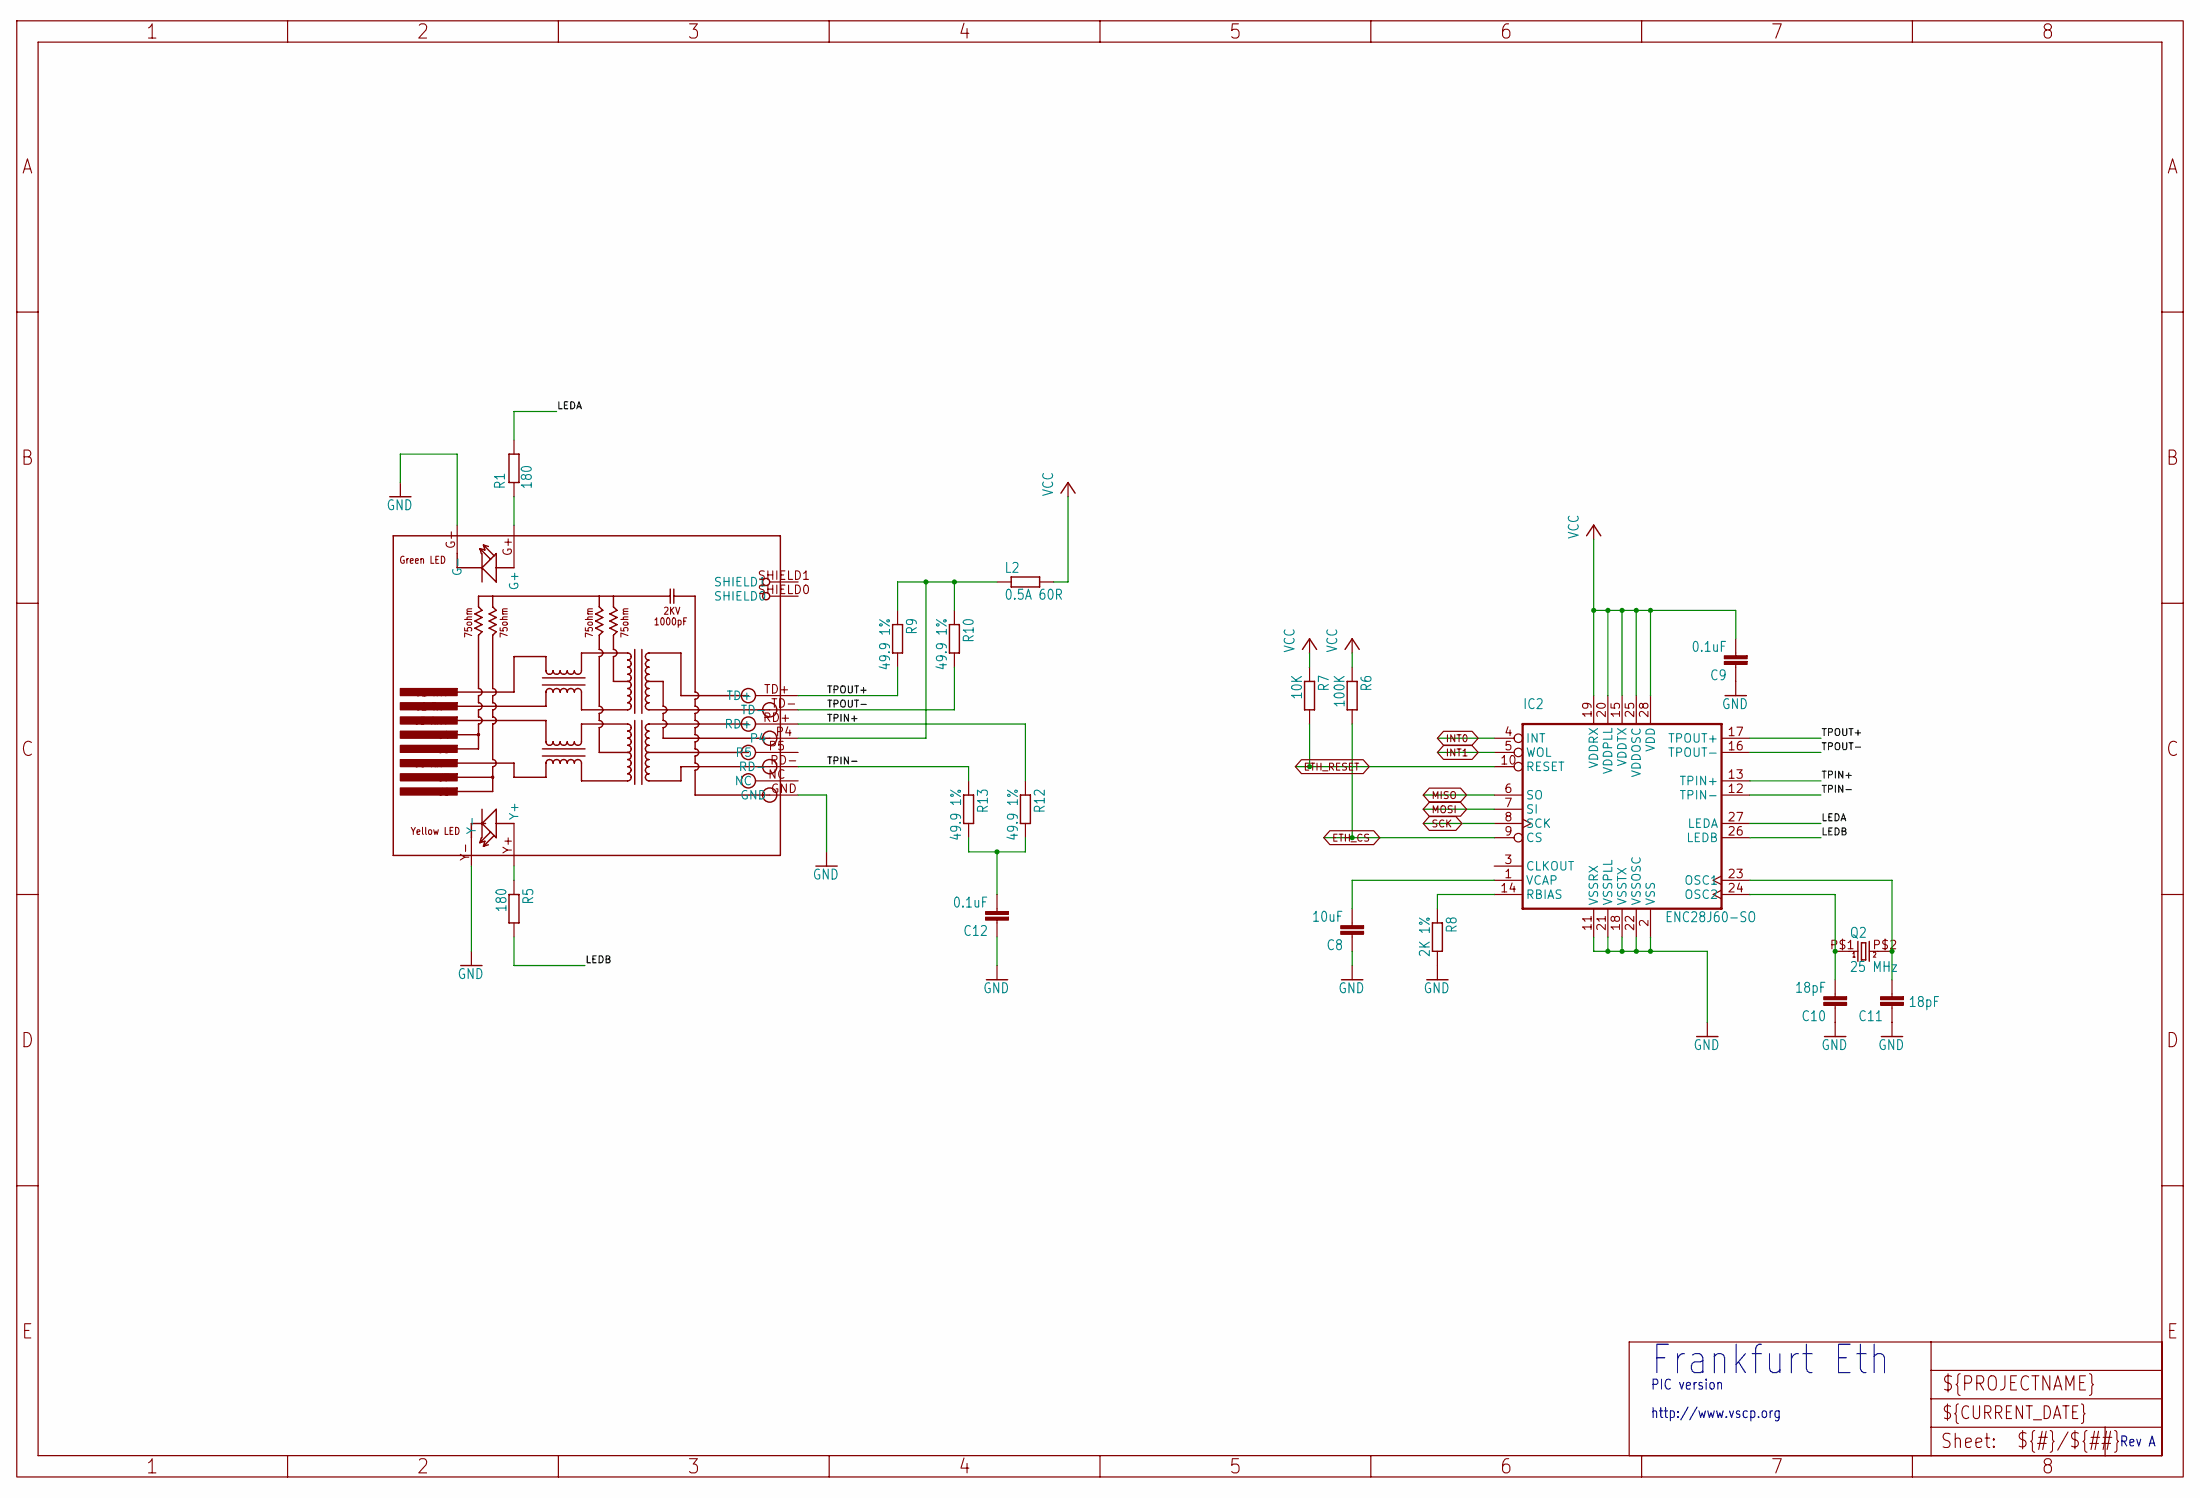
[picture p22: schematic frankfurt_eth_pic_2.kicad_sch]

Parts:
C8: 10uF; C0805
C9, C12: 0.1uF; C0805
C10, C11: 18pF; C0805
IC2: ENC28J60-SO; SO28W
L2: 0.5A 60R; R0805
Q2: 25 MHz; 9C
R1, R5: 180; R0805
R6: 100K; R0805
R7: 10K; R0805
R8: 2K 1%; R0805
R9, R10, R12, R13: 49.9 1%; R0805
RJ1: HR911105A

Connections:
ETH_CS: IC2.9 (CS), R6.2; also elsewhere on the board
ETH_RESET: IC2.10 (RESET), R7.2; also elsewhere on the board
GND: C8.1, C9.1, C10.1, C11.1, C12.1, IC2.2 (VSS), IC2.11 (VSSRX), IC2.18 (VSSTX), IC2.21 (VSSPLL), IC2.22 (VSSOSC), R8.2, RJ1.G-, RJ1.GND, RJ1.Y-; also elsewhere on the board
INT0: IC2.4 (INT); also elsewhere on the board
INT1: IC2.5 (WOL); also elsewhere on the board
LEDA: IC2.27 (LEDA), R1.2
LEDB: IC2.26 (LEDB), R5.2
MISO: IC2.6 (SO); also elsewhere on the board
MOSI: IC2.7 (SI); also elsewhere on the board
unnamed: R1.1, RJ1.G+
unnamed: C8.2, IC2.1 (VCAP)
unnamed: R5.1, RJ1.Y+
unnamed: IC2.14 (RBIAS), R8.1
unnamed: C10.2, IC2.24 (OSC2), Q2.P$1 (1)
unnamed: C11.2, IC2.23 (OSC1), Q2.P$2 (2)
unnamed: C12.2, R12.2, R13.2
unnamed: L2.1, R9.1, R10.1, RJ1.P4
SCK: IC2.8 (SCK); also elsewhere on the board
TPIN+: IC2.13 (TPIN+), R12.1, RJ1.RD+
TPIN-: IC2.12 (TPIN-), R13.1, RJ1.RD-
TPOUT+: IC2.17 (TPOUT+), R9.2, RJ1.TD+
TPOUT-: IC2.16 (TPOUT-), R10.2, RJ1.TD-
VCC: C9.2, IC2.15 (VDDTX), IC2.19 (VDDRX), IC2.20 (VDDPLL), IC2.25 (VDDOSC), IC2.28 (VDD), L2.2, R6.1, R7.1; also elsewhere on the board

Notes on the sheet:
Rev A
Frankfurt Eth
PIC version
http://www.vscp.org

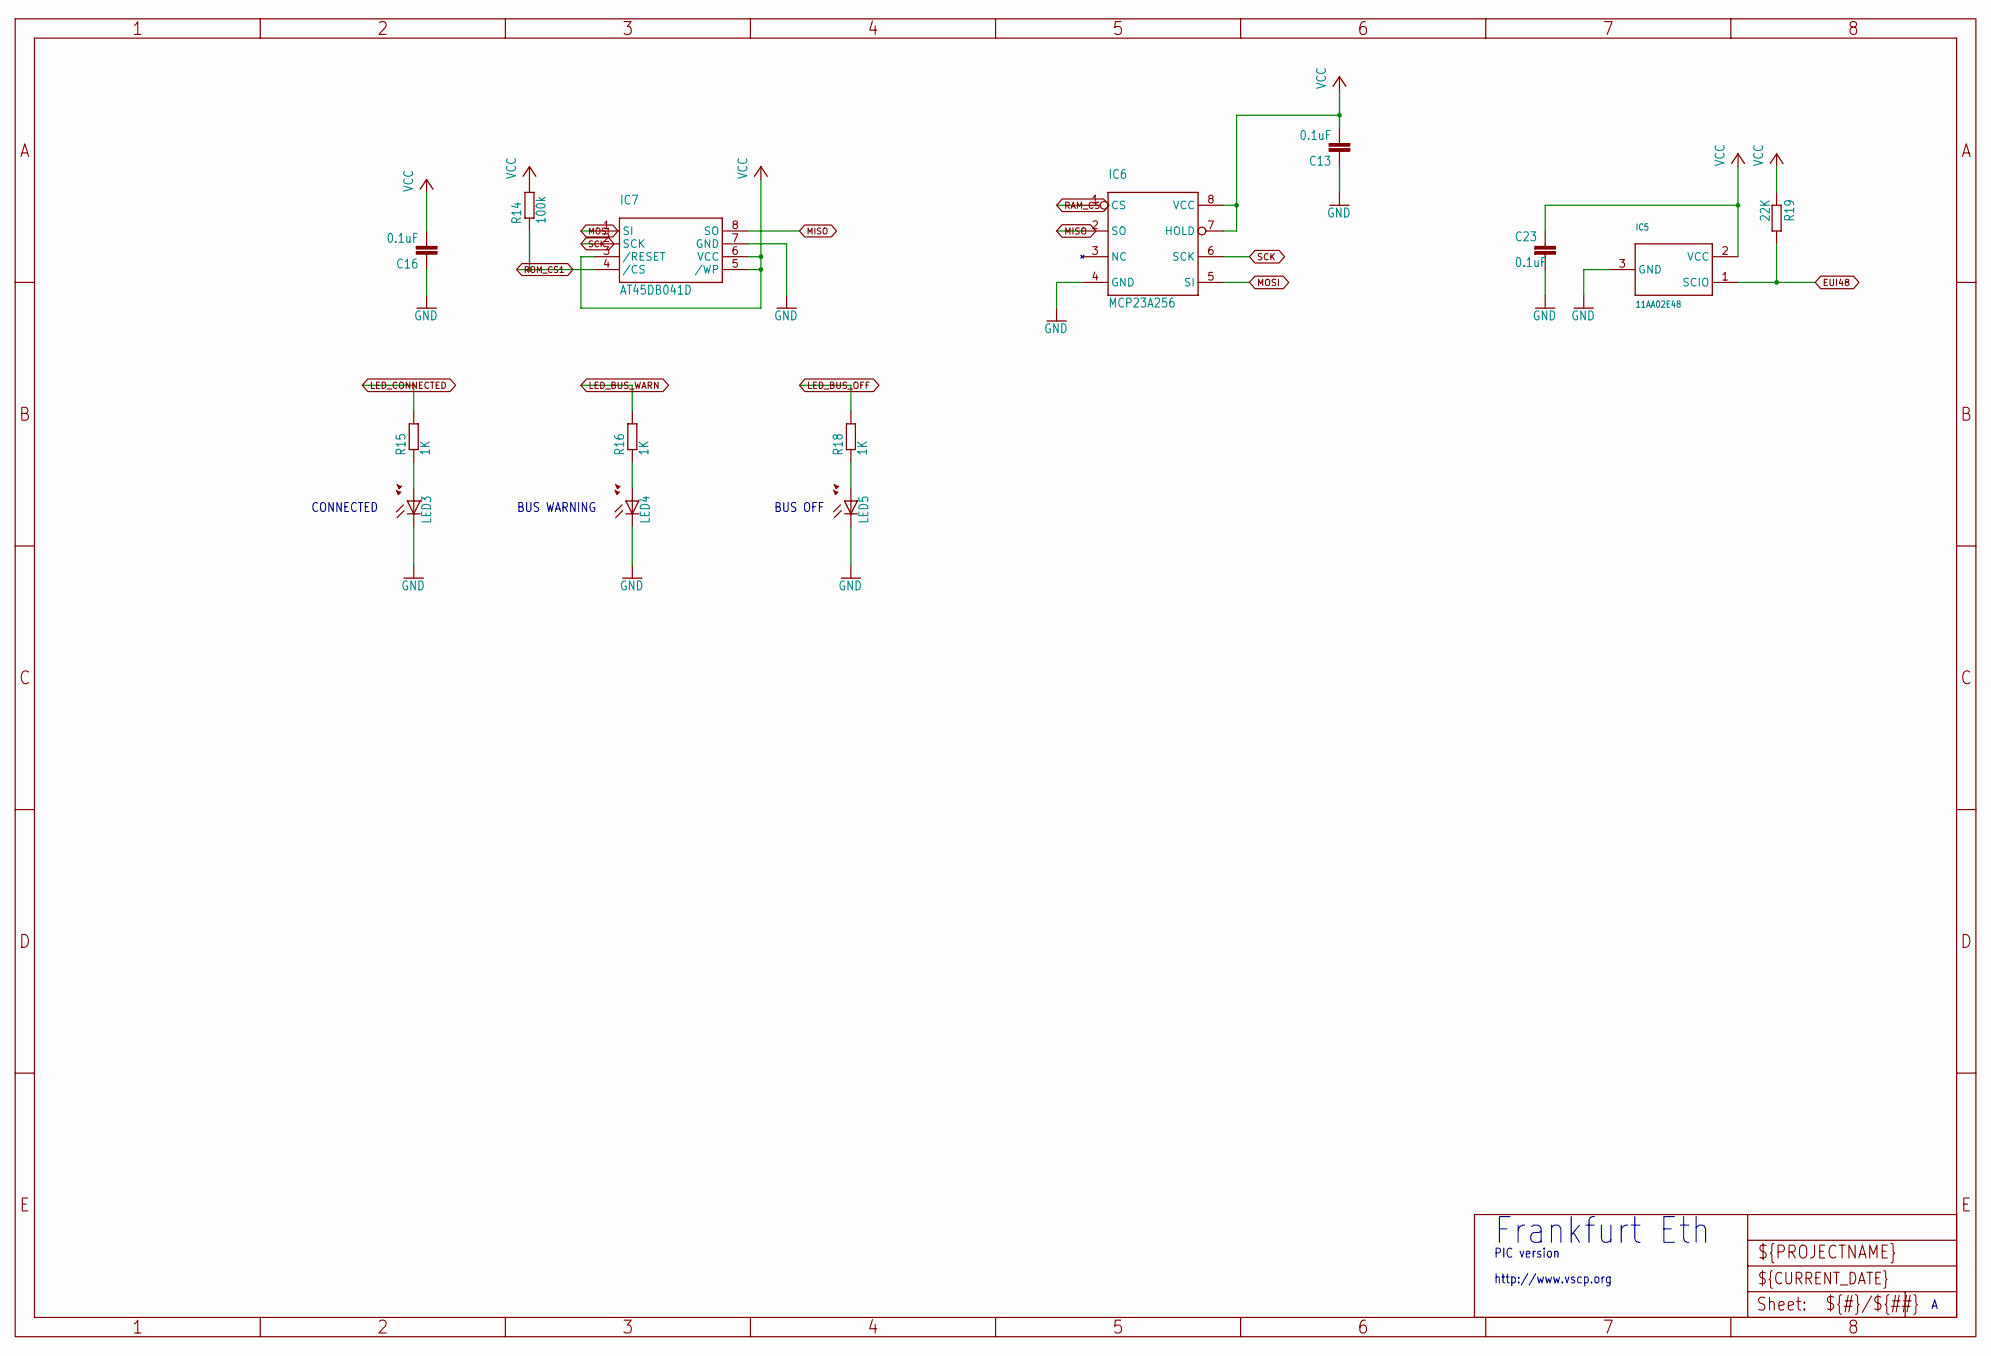
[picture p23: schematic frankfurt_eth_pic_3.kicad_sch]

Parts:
C13, C16, C23: 0.1uF; C0805
IC5: 11AA02E48; SOT23
IC6: MCP23A256; SO-8
IC7: AT45DB041D; SOP8W
LED3, LED4, LED5: LEDCHIP-LED0805; CHIP-LED0805
R14: 100k; M0805
R15, R16, R18: 1K; R0805
R19: 22K; M0805

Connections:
EUI48: IC5.1 (SCIO), R19.2; also elsewhere on the board
GND: C13.1, C16.1, C23.2, IC5.3 (GND), IC6.4 (GND), IC7.7 (GND), LED3.C, LED4.C, LED5.C; also elsewhere on the board
LED_BUS_OFF: R18.2; also elsewhere on the board
LED_BUS_WARN: R16.2; also elsewhere on the board
LED_CONNECTED: R15.2; also elsewhere on the board
MISO: IC6.2 (SO), IC7.8 (SO); also elsewhere on the board
MOSI: IC6.5 (SI), IC7.1 (SI); also elsewhere on the board
unnamed: LED3.A, R15.1
unnamed: LED4.A, R16.1
unnamed: LED5.A, R18.1
RAM_CS: IC6.1 (CS); also elsewhere on the board
ROM_CS1: IC7.4 (/CS), R14.1; also elsewhere on the board
SCK: IC6.6 (SCK), IC7.2 (SCK); also elsewhere on the board
VCC: C13.2, C16.2, C23.1, IC5.2 (VCC), IC6.7 (HOLD), IC6.8 (VCC), IC7.3 (/RESET), IC7.5 (/WP), IC7.6 (VCC), R14.2, R19.1; also elsewhere on the board

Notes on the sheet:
BUS OFF
PIC version
http://www.vscp.org
CONNECTED
BUS WARNING
Frankfurt Eth

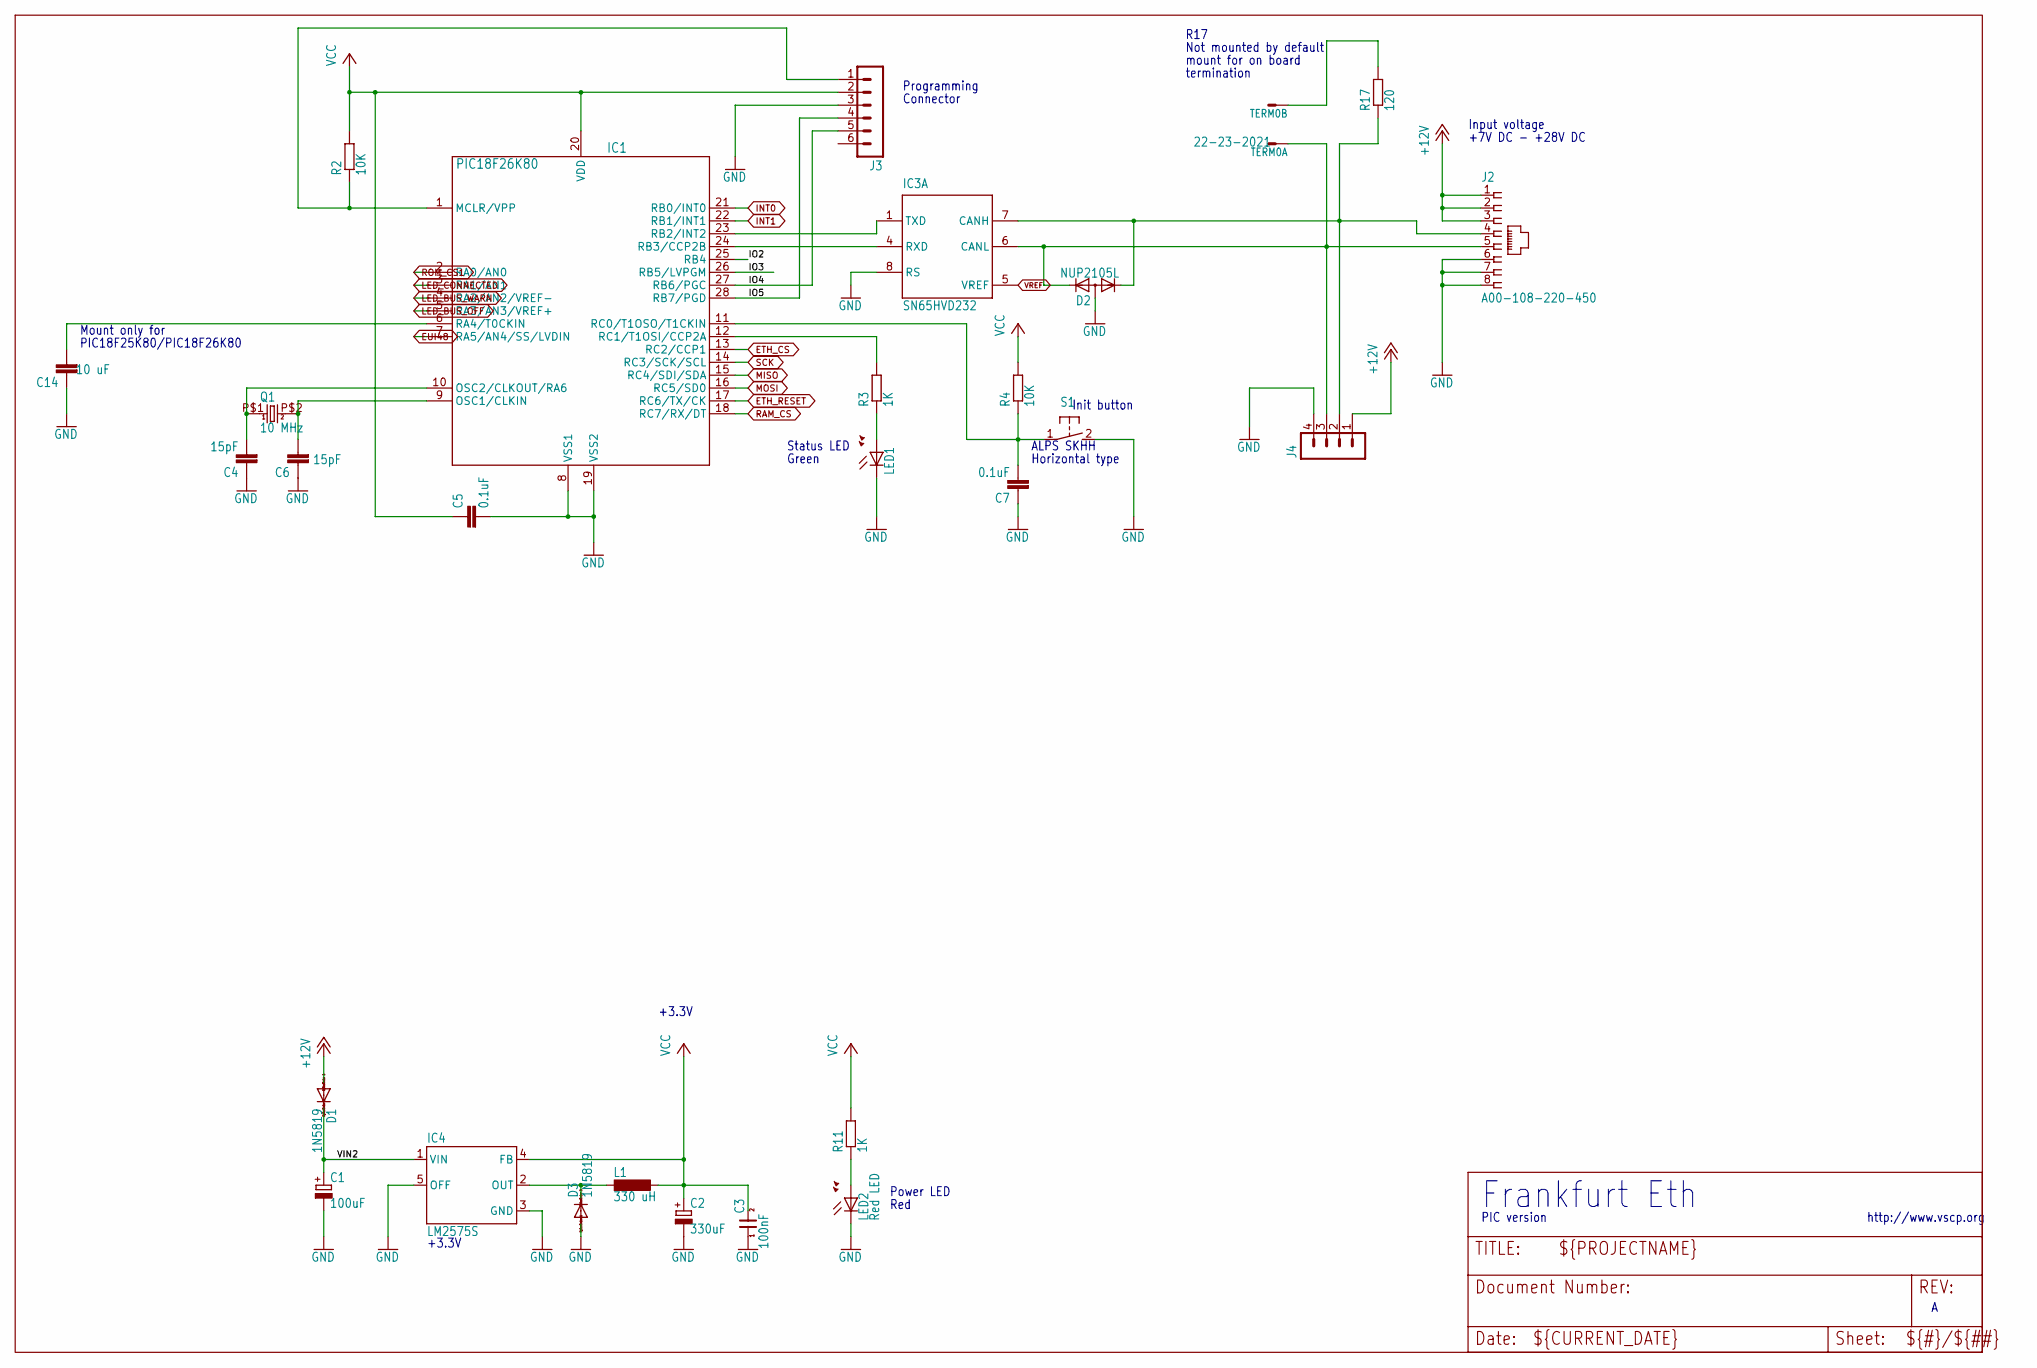
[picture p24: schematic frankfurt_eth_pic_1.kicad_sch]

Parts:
C1: 100uF; PANASONIC_D
C2: 330uF; PANASONIC_D
C3: 100nF; 0805
C4, C6: 15pF; C0805
C5, C7: 0.1uF; C0805
C14: 10 uF; C0805
D1, D3: 1N5819; SOD123
D2: NUP2105L; SOT23
IC1: PIC18F26K80; SO28
IC3: SN65HVD232; SO-08
IC4: LM2575S; TO263-5
J2: A00-108-220-450; RJ-45
J3: MA06-1
J4: MA04-1
L1: 330 uH; DO3316P
LED1: LEDCHIP-LED0805; CHIP-LED0805
LED2: Red LED; CHIP-LED0805
Q1: 10 MHz; 9C
R2, R4: 10K; R0805
R3, R11: 1K; R0805
R17: 120; R0805
S1: 31-XX; B3F-31XX
TERM0: 22-23-2021

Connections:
+12V: D1.A, J2.1, J2.2, J2.3, J4.1
CANL: D2.2 (K2), IC3.6 (CANL), J2.5, J4.3, TERM0.1
ETH_CS: IC1.13 (RC2/CCP1); also elsewhere on the board
ETH_RESET: IC1.17 (RC6/TX/CK); also elsewhere on the board
EUI48: IC1.7 (RA5/AN4/SS/LVDIN); also elsewhere on the board
GND: C1.-, C2.-, C3.1, C4.1, C5.2, C6.1, C7.1, C14.1, D2.3 (A), D3.A, IC1.8 (VSS1), IC1.19 (VSS2), IC3.2 (VSS), IC3.8 (RS), IC4.3 (GND), IC4.5 (OFF), J2.6, J2.7, J2.8, J3.3, J4.4, LED1.C, LED2.C, S1.2 (S); also elsewhere on the board
INT0: IC1.21 (RB0/INT0); also elsewhere on the board
INT1: IC1.22 (RB1/INT1); also elsewhere on the board
IO2: IC1.25 (RB4)
IO3: IC1.26 (RB5/LVPGM)
IO4: IC1.27 (RB6/PGC), J3.5
IO5: IC1.28 (RB7/PGD), J3.4
LED_BUS_OFF: IC1.5 (RA3/AN3/VREF+); also elsewhere on the board
LED_BUS_WARN: IC1.4 (RA2/AN2/VREF-); also elsewhere on the board
LED_CONNECTED: IC1.3 (RA1/AN1); also elsewhere on the board
MISO: IC1.15 (RC4/SDI/SDA); also elsewhere on the board
MOSI: IC1.16 (RC5/SD0); also elsewhere on the board
unnamed: D3.C, IC4.2 (OUT), L1.1
unnamed: C4.2, IC1.10 (OSC2/CLKOUT/RA6), Q1.P$1 (1)
unnamed: C14.2, IC1.6 (RA4/T0CKIN)
unnamed: IC1.12 (RC1/T1OSI/CCP2A), R3.2
unnamed: LED1.A, R3.1
unnamed: C7.2, IC1.11 (RC0/T1OSO/T1CKIN), R4.1, S1.1
unnamed: C6.2, IC1.9 (OSC1/CLKIN), Q1.P$2 (2)
unnamed: R17.2, TERM0.2
unnamed: LED2.A, R11.1
unnamed: D2.1 (K1), IC3.7 (CANH), J2.4, J4.2, R17.1
RAM_CS: IC1.18 (RC7/RX/DT); also elsewhere on the board
RESET: IC1.1 (MCLR/VPP), J3.1, R2.1
ROM_CS1: IC1.2 (RA0/AN0); also elsewhere on the board
RXCAN: IC1.24 (RB3/CCP2B), IC3.4 (RXD)
SCK: IC1.14 (RC3/SCK/SCL); also elsewhere on the board
TXCAN: IC1.23 (RB2/INT2), IC3.1 (TXD)
VCC: C2.+, C3.2, C5.1, IC1.20 (VDD), IC3.3 (VDD), IC4.4 (FB), J3.2, L1.2, R2.2, R4.2, R11.2; also elsewhere on the board
VIN2: C1.+, D1.C, IC4.1 (VIN)
VREF: IC3.5 (VREF)

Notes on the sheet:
Power LED
Status LED
Frankfurt Eth
PIC version
Mount only for
http://www.vscp.org
Not mounted by default
PIC18F25K80/PIC18F26K80
Horizontal type
mount for on board
R17
Red
Programming
ALPS SKHH
termination
+3.3V
Connector
Green
Init button
Input voltage
+7V DC - +28V DC

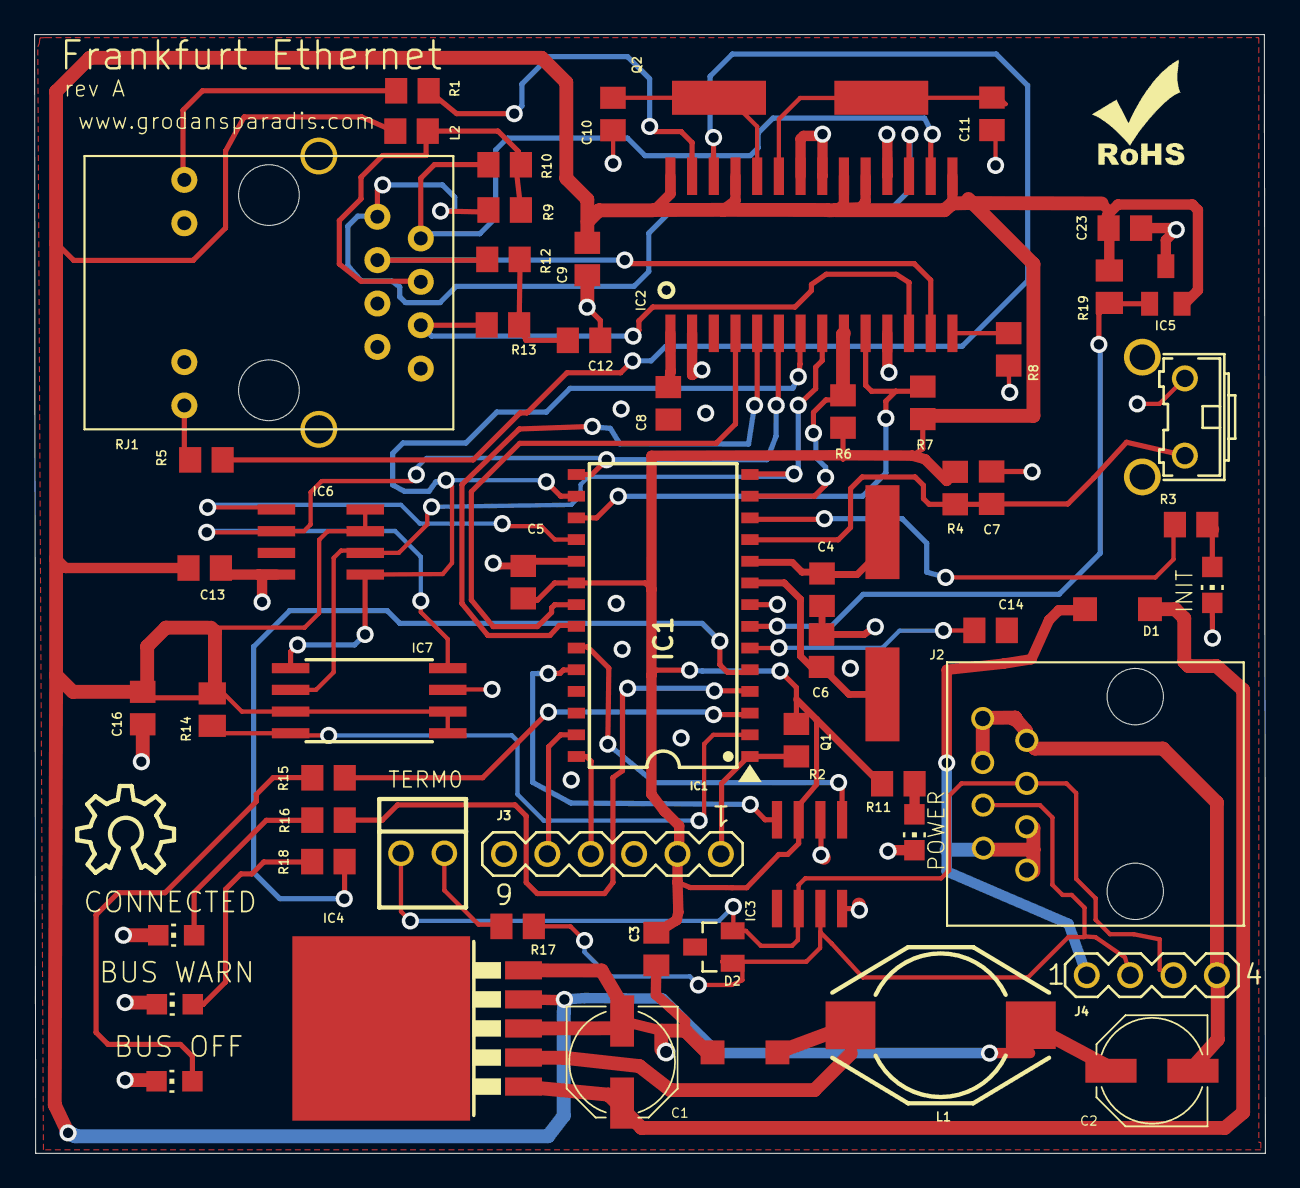
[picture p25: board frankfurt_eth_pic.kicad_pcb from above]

Board: 6 copper layers, 72.1 x 65.5 mm, 62 parts (0 on the bottom side), 50 nets.

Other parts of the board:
U$1: ROHS_SILK
U$2: OSHW_10X200_NOTEXT

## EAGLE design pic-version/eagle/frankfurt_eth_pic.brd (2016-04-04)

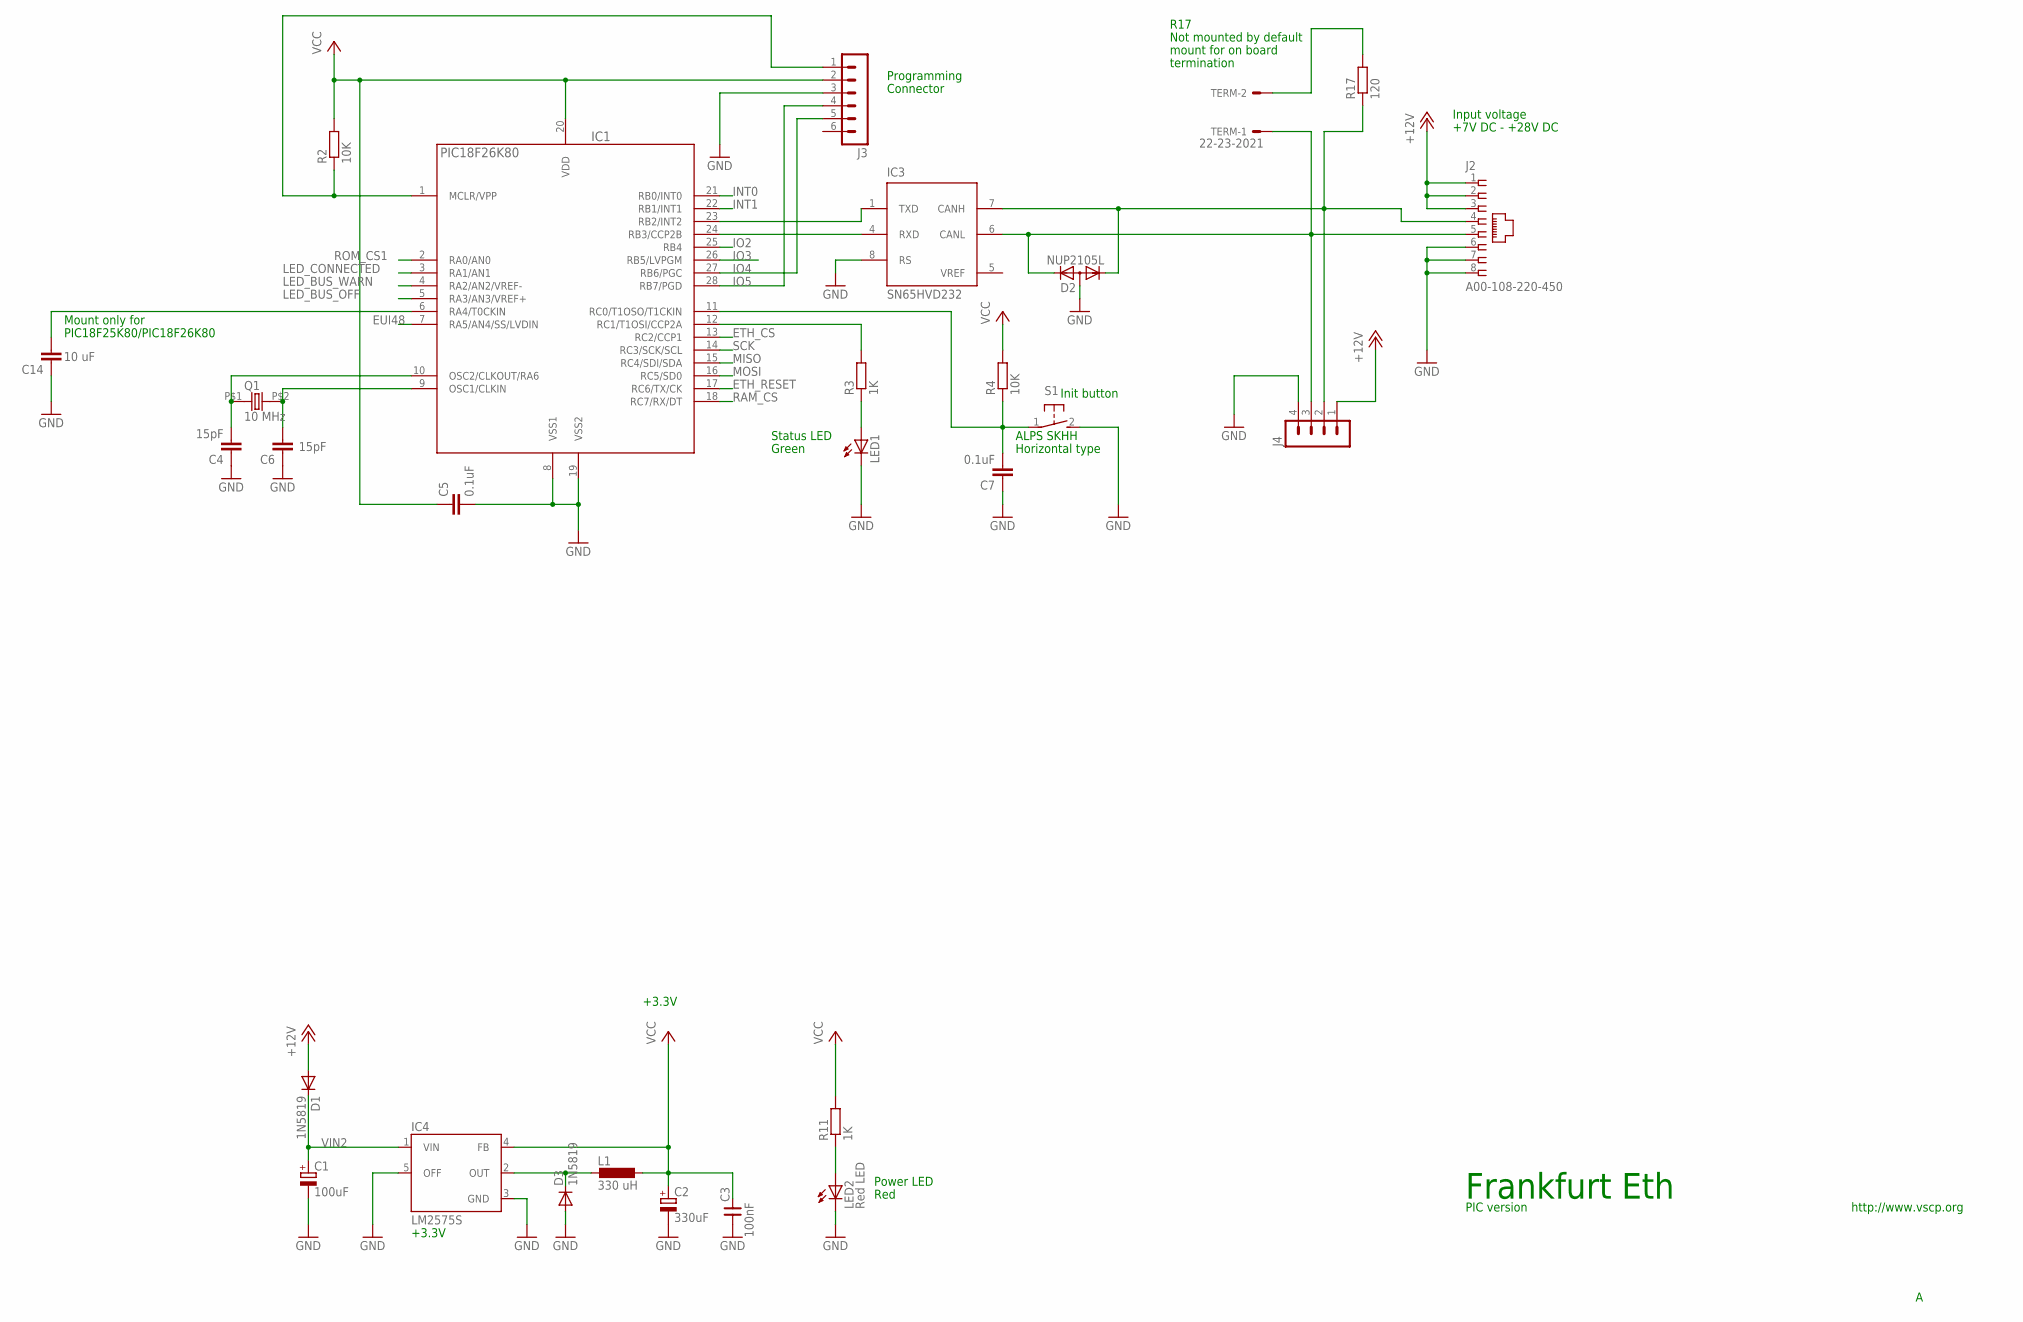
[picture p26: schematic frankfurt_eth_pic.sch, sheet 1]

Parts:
C1: 100uF; PANASONIC_D
C2: 330uF; PANASONIC_D
C3: 100nF; 0805
C4, C6: 15pF; C0805
C5, C7: 0.1uF; C0805
C14: 10 uF; C0805
D1, D3: 1N5819; SOD123
D2: NUP2105L; SOT23
IC1: PIC18F26K80; SO28
IC3: SN65HVD232; SO-08
IC4: LM2575S; TO263-5
J2: A00-108-220-450; RJ-45
J3: MA06-1
J4: MA04-1
L1: 330 uH; DO3316P
LED1: LEDCHIP-LED0805; CHIP-LED0805
LED2: Red LED; CHIP-LED0805
Q1: 10 MHz; 9C
R2, R4: 10K; R0805
R3, R11: 1K; R0805
R17: 120; R0805
S1: 31-XX; B3F-31XX
TERM: 22-23-2021

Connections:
+12V: D1.A, J2.1, J2.2, J2.3, J4.1
CANL: D2.2 (K2), IC3.6 (CANL), J2.5, J4.3, TERM.1
ETH_CS: IC1.13 (RC2/CCP1); also elsewhere on the board
ETH_RESET: IC1.17 (RC6/TX/CK); also elsewhere on the board
EUI48: IC1.7 (RA5/AN4/SS/LVDIN); also elsewhere on the board
GND: C1.-, C2.-, C3.1, C4.1, C5.2, C6.1, C7.1, C14.1, D2.3 (A), D3.A, IC1.8 (VSS1), IC1.19 (VSS2), IC3.2 (VSS), IC3.8 (RS), IC4.3 (GND), IC4.5 (OFF), J2.6, J2.7, J2.8, J3.3, J4.4, LED1.C, LED2.C, S1.2 (S); also elsewhere on the board
INT0: IC1.21 (RB0/INT0); also elsewhere on the board
INT1: IC1.22 (RB1/INT1); also elsewhere on the board
IO2: IC1.25 (RB4)
IO3: IC1.26 (RB5/LVPGM)
IO4: IC1.27 (RB6/PGC), J3.5
IO5: IC1.28 (RB7/PGD), J3.4
LED_BUS_OFF: IC1.5 (RA3/AN3/VREF+); also elsewhere on the board
LED_BUS_WARN: IC1.4 (RA2/AN2/VREF-); also elsewhere on the board
LED_CONNECTED: IC1.3 (RA1/AN1); also elsewhere on the board
MISO: IC1.15 (RC4/SDI/SDA); also elsewhere on the board
MOSI: IC1.16 (RC5/SD0); also elsewhere on the board
unnamed: D3.C, IC4.2 (OUT), L1.1
unnamed: C4.2, IC1.10 (OSC2/CLKOUT/RA6), Q1.P$1 (1)
unnamed: C14.2, IC1.6 (RA4/T0CKIN)
unnamed: IC1.12 (RC1/T1OSI/CCP2A), R3.2
unnamed: LED1.A, R3.1
unnamed: C7.2, IC1.11 (RC0/T1OSO/T1CKIN), R4.1, S1.1
unnamed: C6.2, IC1.9 (OSC1/CLKIN), Q1.P$2 (2)
unnamed: R17.2, TERM.2
unnamed: LED2.A, R11.1
unnamed: D2.1 (K1), IC3.7 (CANH), J2.4, J4.2, R17.1
RAM_CS: IC1.18 (RC7/RX/DT); also elsewhere on the board
RESET: IC1.1 (MCLR/VPP), J3.1, R2.1
ROM_CS1: IC1.2 (RA0/AN0); also elsewhere on the board
RXCAN: IC1.24 (RB3/CCP2B), IC3.4 (RXD)
SCK: IC1.14 (RC3/SCK/SCL); also elsewhere on the board
TXCAN: IC1.23 (RB2/INT2), IC3.1 (TXD)
VCC: C2.+, C3.2, C5.1, IC1.20 (VDD), IC3.3 (VDD), IC4.4 (FB), J3.2, L1.2, R2.2, R4.2, R11.2; also elsewhere on the board
VIN2: C1.+, D1.C, IC4.1 (VIN)
VREF: IC3.5 (VREF)

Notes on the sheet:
Init button
Status LED
Programming
Connector
ALPS SKHH
Horizontal type
Input voltage
+7V DC - +28V DC
Power LED
Red
Green
Mount only for
PIC18F25K80/PIC18F26K80
Not mounted by default
mount for on board
termination
R17
+3.3V
Frankfurt Eth
http://www.vscp.org
PIC version

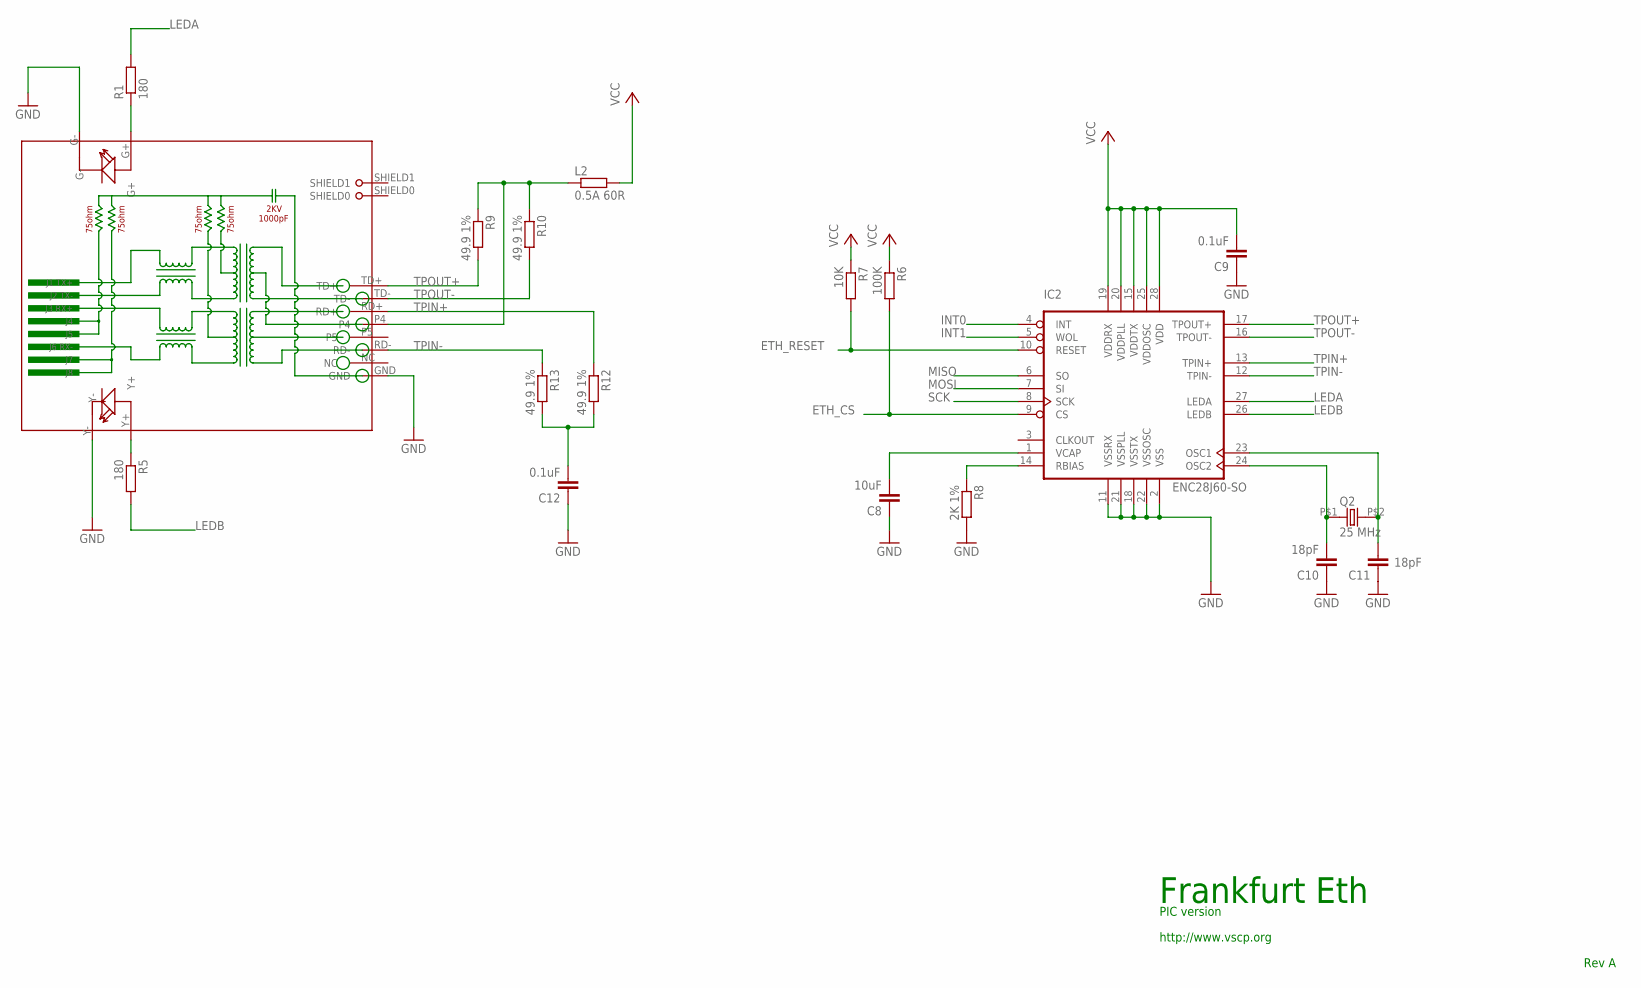
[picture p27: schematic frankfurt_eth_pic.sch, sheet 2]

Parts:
C8: 10uF; C0805
C9, C12: 0.1uF; C0805
C10, C11: 18pF; C0805
IC2: ENC28J60-SO; SO28W
L2: 0.5A 60R; R0805
Q2: 25 MHz; 9C
R1, R5: 180; R0805
R6: 100K; R0805
R7: 10K; R0805
R8: 2K 1%; R0805
R9, R10, R12, R13: 49.9 1%; R0805
RJ1: HR911105A

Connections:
ETH_CS: IC2.9 (CS), R6.2; also elsewhere on the board
ETH_RESET: IC2.10 (RESET), R7.2; also elsewhere on the board
GND: C8.1, C9.1, C10.1, C11.1, C12.1, IC2.2 (VSS), IC2.11 (VSSRX), IC2.18 (VSSTX), IC2.21 (VSSPLL), IC2.22 (VSSOSC), R8.2, RJ1.G-, RJ1.GND, RJ1.Y-; also elsewhere on the board
INT0: IC2.4 (INT); also elsewhere on the board
INT1: IC2.5 (WOL); also elsewhere on the board
LEDA: IC2.27 (LEDA), R1.2
LEDB: IC2.26 (LEDB), R5.2
MISO: IC2.6 (SO); also elsewhere on the board
MOSI: IC2.7 (SI); also elsewhere on the board
unnamed: R1.1, RJ1.G+
unnamed: C8.2, IC2.1 (VCAP)
unnamed: R5.1, RJ1.Y+
unnamed: IC2.14 (RBIAS), R8.1
unnamed: C10.2, IC2.24 (OSC2), Q2.P$1 (1)
unnamed: C11.2, IC2.23 (OSC1), Q2.P$2 (2)
unnamed: C12.2, R12.2, R13.2
unnamed: L2.1, R9.1, R10.1, RJ1.P4
SCK: IC2.8 (SCK); also elsewhere on the board
TPIN+: IC2.13 (TPIN+), R12.1, RJ1.RD+
TPIN-: IC2.12 (TPIN-), R13.1, RJ1.RD-
TPOUT+: IC2.17 (TPOUT+), R9.2, RJ1.TD+
TPOUT-: IC2.16 (TPOUT-), R10.2, RJ1.TD-
VCC: C9.2, IC2.15 (VDDTX), IC2.19 (VDDRX), IC2.20 (VDDPLL), IC2.25 (VDDOSC), IC2.28 (VDD), L2.2, R6.1, R7.1; also elsewhere on the board

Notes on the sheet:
Rev A
Frankfurt Eth
http://www.vscp.org
PIC version

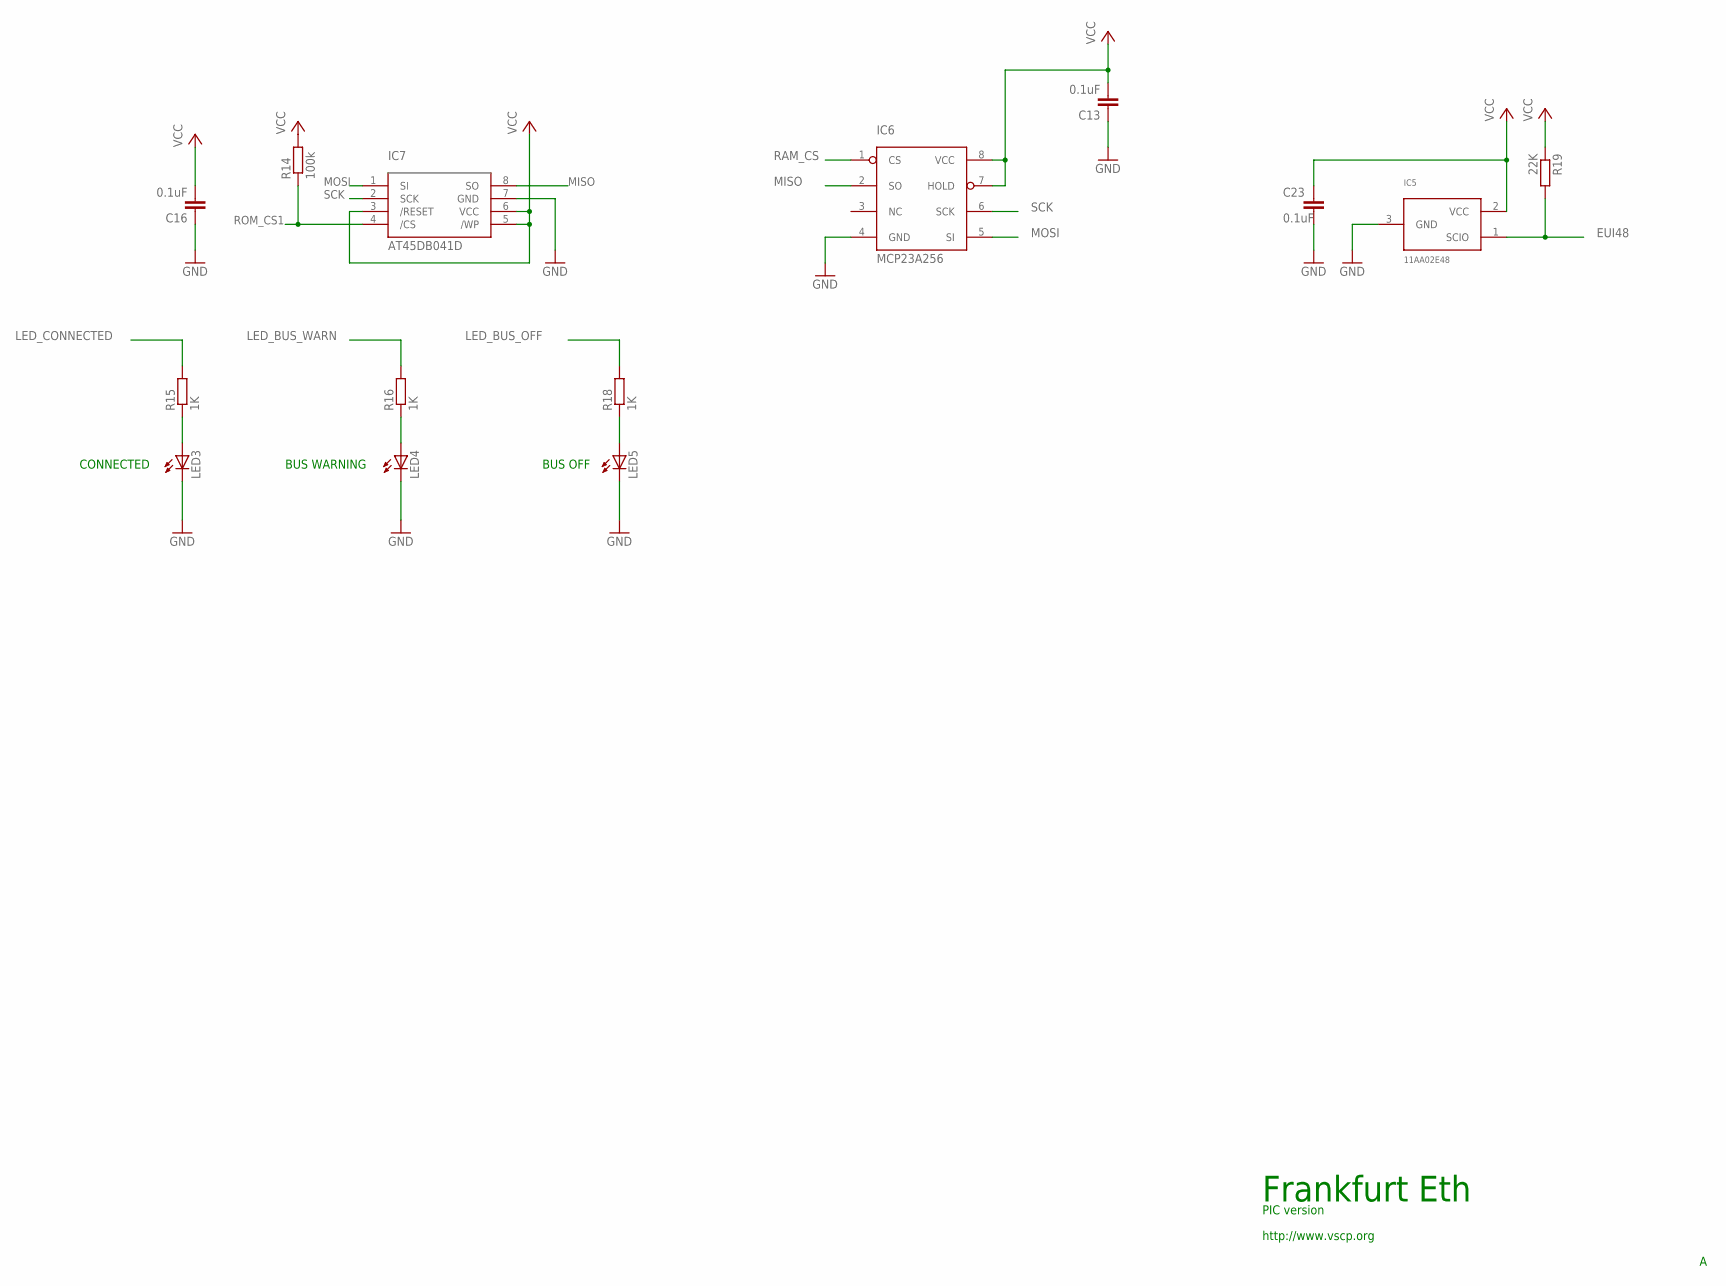
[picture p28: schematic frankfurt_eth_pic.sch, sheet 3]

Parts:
C13, C16, C23: 0.1uF; C0805
IC5: 11AA02E48; SOT23
IC6: MCP23A256; SO-8
IC7: AT45DB041D; SOP8W
LED3, LED4, LED5: LEDCHIP-LED0805; CHIP-LED0805
R14: 100k; M0805
R15, R16, R18: 1K; R0805
R19: 22K; M0805

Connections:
EUI48: IC5.1 (SCIO), R19.2; also elsewhere on the board
GND: C13.1, C16.1, C23.2, IC5.3 (GND), IC6.4 (GND), IC7.7 (GND), LED3.C, LED4.C, LED5.C; also elsewhere on the board
LED_BUS_OFF: R18.2; also elsewhere on the board
LED_BUS_WARN: R16.2; also elsewhere on the board
LED_CONNECTED: R15.2; also elsewhere on the board
MISO: IC6.2 (SO), IC7.8 (SO); also elsewhere on the board
MOSI: IC6.5 (SI), IC7.1 (SI); also elsewhere on the board
unnamed: LED3.A, R15.1
unnamed: LED4.A, R16.1
unnamed: LED5.A, R18.1
RAM_CS: IC6.1 (CS); also elsewhere on the board
ROM_CS1: IC7.4 (/CS), R14.1; also elsewhere on the board
SCK: IC6.6 (SCK), IC7.2 (SCK); also elsewhere on the board
VCC: C13.2, C16.2, C23.1, IC5.2 (VCC), IC6.7 (HOLD), IC6.8 (VCC), IC7.3 (/RESET), IC7.5 (/WP), IC7.6 (VCC), R14.2, R19.1; also elsewhere on the board

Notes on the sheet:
CONNECTED
BUS WARNING
BUS OFF
Frankfurt Eth
http://www.vscp.org
PIC version


Board: 2 copper layers, 72.1 x 65.5 mm, 62 parts (0 on the bottom side), 50 nets.

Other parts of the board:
U$1: ROHS_SILK
U$2: OSHW_10X200_NOTEXT

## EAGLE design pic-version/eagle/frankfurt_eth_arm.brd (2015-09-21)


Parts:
BOOT0, BOOT1: MA03-1
C1: 100uF; PANASONIC_D
C2: 330uF; PANASONIC_D
C3: 100nF; 0805
C4, C6, C20, C21: 22pF; C0805
C5, C7, C14, C15, C17, C18, C19: 0.1uF; C0805
D1, D3: 1N5819; SOD123
D2: NUP2105L; SOT23
IC1: STM32F103C6T7A; QFP50P900X900X160-48N
IC3: SN65HVD232; SO-08
IC4: LM2575S; TO263-5
J1: MA05-2
J2: A00-108-220-450; RJ-45
J3: SJ
J4: MA04-1
J5: TAMPER; 22-23-2021
L1: 330 uH; DO3316P
LED1: LEDCHIP-LED0805; CHIP-LED0805
LED2: Red LED; CHIP-LED0805
R2: 100K; R0805
R3, R4, R23, R25, R26, R27, R28: 10K; R0805
R11: 1K; R0805
R17: 120; R0805
R20, R21: 33K; R0805
R22: 1M; R0805
S1: 31-XX; B3F-31XX
TERM: 22-23-2021
UART1: 22-23-2041
X1: 8 MHz; 9C
X2: 32768 hZ; TC26H

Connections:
+12V: D1.A, J2.1, J2.2, J2.3, J4.1
BOOT0: IC1.44 (BOOT0), R20.2
BOOT1: IC1.20 (PB2), R21.2
CANL: D2.2 (K2), IC3.5 (VREF), IC3.6 (CANL), J2.5, J4.3, TERM.1
CANRXD: IC1.32 (PA11), IC3.4 (RXD)
CANTXD: IC1.33 (PA12), IC3.1 (TXD)
ETH_CS: IC1.14 (PA4); also elsewhere on the board
ETH_INT0: IC1.45 (PB8); also elsewhere on the board
ETH_INT1: IC1.46 (PB9); also elsewhere on the board
ETH_RESET: IC1.28 (PB15); also elsewhere on the board
EUI48: IC1.22 (PB11); also elsewhere on the board
GND: BOOT0.1, BOOT1.1, C1.-, C2.-, C3.1, C4.1, C5.2, C6.1, C7.1, C14.2, C15.2, C17.2, C18.2, C19.2, C20.1, C21.1, D2.3 (A), D3.A, IC1.8 (VSSA), IC1.23 (VSS_1), IC1.35 (VSS_2), IC1.47 (VSS_3), IC3.2 (VSS), IC3.8 (RS), IC4.3 (GND), IC4.5 (OFF), J1.3, J1.5, J1.7, J1.9, J2.6, J2.7, J2.8, J4.4, J5.2, LED1.C, LED2.C, S1.2 (S), UART1.4; also elsewhere on the board
INIT: IC1.26 (PB13), R3.2
INITSW: C7.2, IC1.27 (PB14), R4.1, S1.1
LED_BUS_WARN: IC1.25 (PB12)
MISO: IC1.16 (PA6); also elsewhere on the board
MOSI: IC1.17 (PA7); also elsewhere on the board
unnamed: D3.C, IC4.2 (OUT), L1.1
unnamed: C4.2, IC1.5 (PD0-OSC_IN), R22.2, X1.P$1 (1)
unnamed: LED1.A, R3.1
unnamed: C6.2, IC1.6 (PD1-OSC_OUT), R22.1, X1.P$2 (2)
unnamed: R17.2, TERM.2
unnamed: LED2.A, R11.1
unnamed: D2.1 (K1), IC3.7 (CANH), J2.4, J4.2, R17.1
unnamed: C14.1, IC1.2 (PC13-TAMPER-RTC), J5.1, R23.1
OCS32_OUT: C20.2, IC1.4 (PC15-OSC32_OUT), X2.1
OSC32_IN: C21.2, IC1.3 (PC14-OSC32_IN), X2.2
RAM_CS: IC1.21 (PB10); also elsewhere on the board
ROM_CS1: IC1.13 (PA3); also elsewhere on the board
RST: C5.1, IC1.7 (NRST), J3.2, R2.1
SCK: IC1.15 (PA5); also elsewhere on the board
SWDIO/TMS: IC1.34 (PA13), J1.2, R25.1
TCK/SWCK: IC1.37 (PA14), J1.4, R26.1
TDI: IC1.38 (PA15), J1.8, R28.1
TDO/SWO: IC1.39 (PB3), J1.6, R27.1
TRST: IC1.40 (PB4), J1.10, J3.1
UART1_RX: IC1.31 (PA10), UART1.2
UART1_TX: IC1.30 (PA9), UART1.3
VCC: BOOT0.3, BOOT1.3, C2.+, C3.2, C15.1, C17.1, C18.1, C19.1, IC1.1 (VBAT), IC1.9 (VDDA), IC1.24 (VDD_1), IC1.36 (VDD_2), IC1.48 (VDD_3), IC3.3 (VDD), IC4.4 (FB), J1.1, L1.2, R2.2, R4.2, R11.2, R23.2, R25.2, R26.2, R27.2, R28.2, UART1.1; also elsewhere on the board
VIN2: C1.+, D1.C, IC4.1 (VIN)
_BOOT0: BOOT0.2, R20.1
_BOOT1: BOOT1.2, R21.1

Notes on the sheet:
Init button
Status LED
ALPS SKHH
Horizontal type
Frankfurt Eth
http://www.vscp.org
ARM version
Input voltage
+7V DC - +28V DC
Power LED
Red
Green
Not mounted by default
mount for on board
termination
R17
+3.3V
JTAG 10-pin


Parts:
C8: 10uF; C0805
C9, C12: 0.1uF; C0805
C10, C11: 18pF; C0805
IC2: ENC28J60-SO; SO28W
L2: 0.5A 60R; R0805
R1, R5: 180; R0805
R6: 100K; R0805
R7, R24, R29: 10K; R0805
R8: 2K 1%; R0805
R9, R10, R12, R13: 49.9 1%; R0805
RJ1: HR911105A
X3: 25 MHz; 9C

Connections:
ETH_CS: IC2.9 (CS), R6.2; also elsewhere on the board
ETH_INT0: IC2.4 (INT), R24.2; also elsewhere on the board
ETH_INT1: IC2.5 (WOL), R29.2; also elsewhere on the board
ETH_RESET: IC2.10 (RESET), R7.2; also elsewhere on the board
GND: C8.1, C9.1, C10.1, C11.1, C12.1, IC2.2 (VSS), IC2.11 (VSSRX), IC2.18 (VSSTX), IC2.21 (VSSPLL), IC2.22 (VSSOSC), R8.2, RJ1.G-, RJ1.GND, RJ1.Y-; also elsewhere on the board
LEDA: IC2.27 (LEDA), R1.2
LEDB: IC2.26 (LEDB), R5.2
MISO: IC2.6 (SO); also elsewhere on the board
MOSI: IC2.7 (SI); also elsewhere on the board
unnamed: R1.1, RJ1.G+
unnamed: C8.2, IC2.1 (VCAP)
unnamed: R5.1, RJ1.Y+
unnamed: IC2.14 (RBIAS), R8.1
unnamed: C10.2, IC2.24 (OSC2), X3.P$1 (1)
unnamed: C11.2, IC2.23 (OSC1), X3.P$2 (2)
unnamed: C12.2, R12.2, R13.2
unnamed: L2.1, R9.1, R10.1, RJ1.P4
SCK: IC2.8 (SCK); also elsewhere on the board
TPIN+: IC2.13 (TPIN+), R12.1, RJ1.RD+
TPIN-: IC2.12 (TPIN-), R13.1, RJ1.RD-
TPOUT+: IC2.17 (TPOUT+), R9.2, RJ1.TD+
TPOUT-: IC2.16 (TPOUT-), R10.2, RJ1.TD-
VCC: C9.2, IC2.15 (VDDTX), IC2.19 (VDDRX), IC2.20 (VDDPLL), IC2.25 (VDDOSC), IC2.28 (VDD), L2.2, R6.1, R7.1, R24.1, R29.1; also elsewhere on the board

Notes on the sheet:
Rev A
Frankfurt Eth
http://www.vscp.org
ARM version


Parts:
C13, C16, C23: 0.1uF; C0805
IC5: 11AA02E48; SOT23
IC6: MCP23A256; SO-8
IC7: AT45DB041D; SOP8W
R14: 100k; M0805
R19: 22K; M0805

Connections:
EUI48: IC5.1 (SCIO), R19.2; also elsewhere on the board
GND: C13.1, C16.1, C23.2, IC5.3 (GND), IC6.4 (GND), IC7.7 (GND); also elsewhere on the board
MISO: IC6.2 (SO), IC7.8 (SO); also elsewhere on the board
MOSI: IC6.5 (SI), IC7.1 (SI); also elsewhere on the board
RAM_CS: IC6.1 (CS); also elsewhere on the board
ROM_CS1: IC7.4 (/CS), R14.1; also elsewhere on the board
SCK: IC6.6 (SCK), IC7.2 (SCK); also elsewhere on the board
VCC: C13.2, C16.2, C23.1, IC5.2 (VCC), IC6.7 (HOLD), IC6.8 (VCC), IC7.3 (/RESET), IC7.5 (/WP), IC7.6 (VCC), R14.2, R19.1; also elsewhere on the board

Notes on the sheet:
BUS OFF
Frankfurt Eth
http://www.vscp.org
ARM version


Board: 2 copper layers, 71.7 x 65.1 mm, 78 parts (0 on the bottom side), 55 nets.

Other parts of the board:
U$1: ROHS_SILK
U$2: OSHW_10X200_NOTEXT

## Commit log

2015-08-26 Added first version of hardware board
    [can4vscp_eth_rev_A.brd, can4vscp_eth_rev_A.sch, frankfurt_eth_rev_A.brd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]
2015-08-26 Removed old folders
    [can4vscp_eth_rev_A.brd, can4vscp_eth_rev_A.sch, frankfurt_eth_rev_A.brd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]
2015-08-31 Started ARM version
    [frankfurt_eth_arm.brd, frankfurt_eth_arm.sch]
2015-09-01 Removed extra status LED's
    [frankfurt_eth_arm.brd, frankfurt_eth_arm.sch]
2015-09-01 edit text layer
    [frankfurt_eth_arm.brd, frankfurt_eth_arm.sch]
2015-09-01 Renamed PIC version
    [frankfurt_eth_pic.brd, frankfurt_eth_pic.sch]
2015-09-02 Added Gerbers
    [frankfurt_eth_arm.brd]
2015-09-02 Moved out R14 a bit
    [frankfurt_eth_arm.brd]
2015-09-02 Updated rev texts
    [frankfurt_eth_arm.sch, frankfurt_eth_pic.sch]
2015-09-02 Added board and schema pictures
2015-09-21 Increase width of vcc for uart connector
    [frankfurt_eth_arm.brd]
2015-09-25 New Gerbers
2015-10-20 Changed layer for info text on pic board
    [frankfurt_eth_pic.brd]
2015-11-13 Rearranged folders
    [frankfurt_eth_arm.brd, frankfurt_eth_arm.sch, frankfurt_eth_pic.brd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]
2016-04-04 Changed value of C14 to 10uF
    [frankfurt_eth_pic.brd, frankfurt_eth_pic.sch]
2023-03-03 Added eps32 version
    [frakfurt_eth.kicad_pcb, frakfurt_eth.kicad_sch]
2023-03-06 ESP32 version 1 preliminary done
    [frakfurt_eth.kicad_pcb]
2023-03-06 Added history file
    [frakfurt_eth.csv, frakfurt_eth.kicad_pcb, frakfurt_eth.kicad_sch]
2023-03-06 Fixed README
    [frakfurt_eth.kicad_sch]
2023-03-06 Added pdf schemas for poe version
    [frakfurt_eth.kicad_sch]
2023-03-07 Added link to pcbway
2023-03-07 Added pcbway logo
2023-04-25 Added POE version
    [frakfurt_eth.csv, frakfurt_eth_jlcpcb.ods]
2025-09-19 Translated schemas to KiCad format
    [can.kicad_sch, cpu.kicad_sch, ethernet.kicad_sch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]
2025-09-19 Added som inital level II build code
    [cpu.kicad_sch]
